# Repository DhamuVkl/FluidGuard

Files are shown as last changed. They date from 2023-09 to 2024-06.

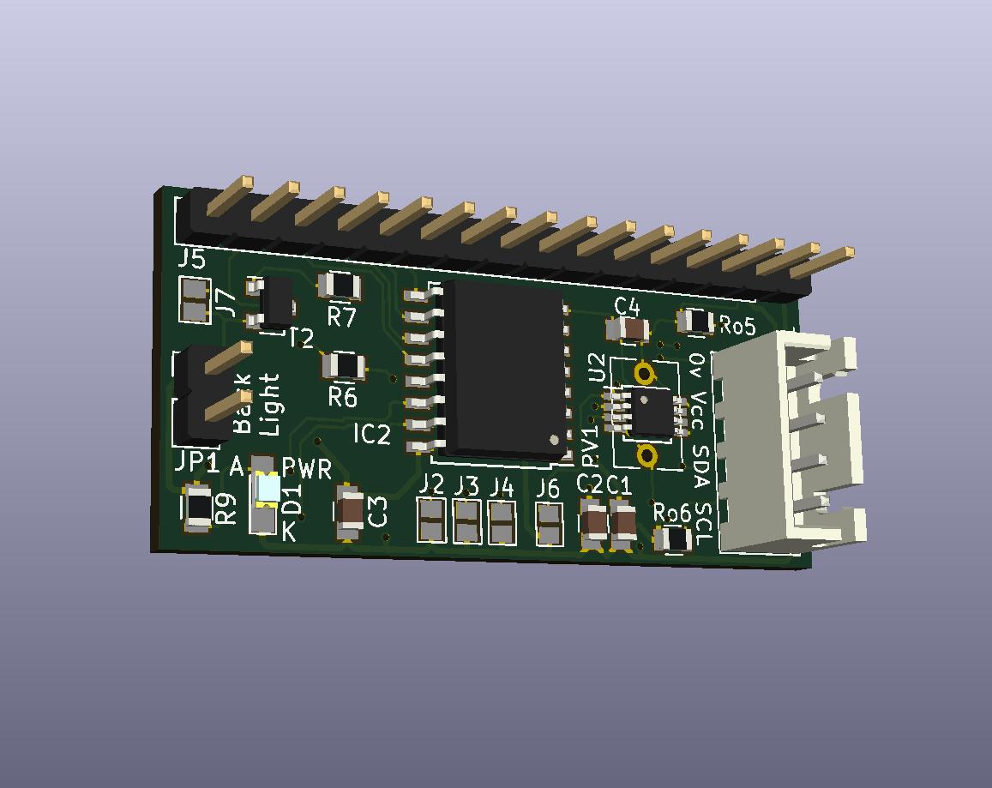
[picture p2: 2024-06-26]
FluidGuard-RX-PCB/Datasheets/I2C_LCD_Controller_Module-master/PCB/LCD_Controller/LCD_Controller3D.jpg

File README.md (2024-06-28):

<br/>
<p align="center">
  <a href="https://github.com/dhamuvkl/FluidGuard">
    
  </a>

  <h1 align="center">FluidGuard</h1>

  <p align="center">
    Envision a helpful companion that not only observes fluid levels but also takes proactive measures to prevent wastage and shortages!
    <br/>
    <br/>
  </p>
</p>

     

## Table Of Contents

* [About the Project](#about-the-project)
* [Key Features](#key-features)
* [Technologies Used](#technologies-used)
* [Schematics and Fabrication](#schematics-and-fabrication)
* [Roadmap](#roadmap)
* [Contributing](#contributing)
* [License](#license)
* [Conclusion](#conclusion)
* [Author](#author)

## About The Project



 <font size= “1”> **The FluidGuard:** </font> Intelligent Liquid Level Management and Refill Solution is akin to having a smart assistant for effectively managing liquids in tanks and containers. Envision a helpful companion that not only observes fluid levels but also takes proactive measures to prevent wastage and shortages, all the while being remarkably dependable and comprehensible. It tackles the challenges associated with manual fluid level management by seamlessly integrating an array of sensors, microcontrollers, wireless communication modules, and control mechanisms. This integration results in a sophisticated approach to fluid monitoring and regulation. Its significance shines in scenarios where precise fluid level management proves pivotal, such as within industrial, agricultural, and distant locations.

##  Key Features: 
coding

*	**Real-time Fluid Level Monitoring:** This system is engineered to monitor liquid levels across various environments, ranging from water tanks to industrial storage. By constantly gathering data from the fluid level sensor, it achieves precise and up-to-the-minute monitoring of fluid levels.
  
*	**Fail-safe Mechanisms:** To guarantee the system's integrity, fail-safe mechanisms are integrated. These mechanisms address potential issues such as data loss or transmission failures, ensuring the system remains operational and dependable.
  
*	**Error Detection and Correction:** The system's intelligence extends to error detection and real-time correction. It can identify sensor errors and implement corrective actions, contributing to its reliability and accuracy.
  
*	**Wireless Communication:** The NRF24L01+ PA/LNA modules serve as the communication backbone between the transmitting and receiving devices. These modules operate on a reliable wireless protocol, enabling seamless data transmission over distances, even in challenging environments.

*	**Automated Fluid Regulation:** Through relay components, the system automatically controls the pump to maintain fluid levels within pre-defined thresholds. This ensures efficient resource utilization and prevents overflows or depletion of the fluid source.
  
*	**User-friendly Interface:** The project incorporates a 16x2 LCD display that presents fluid levels visually using bars and percentages. This intuitive interface enhances user experience and simplifies the interpretation of fluid data.
  
*	**Versatility Across Storage Scenarios:** The system's adaptability makes it suitable for various storage scenarios, including silos and distant locations. Its wireless nature ensures that fluid data can be accessed and managed from a central location, saving time and resources.

## Technologies Used:
coding

*	**Microcontroller (Atmega 328p):** The microcontroller serves as the project's core, processing data from the sensor and facilitating communication with the wireless module.
  
*	**Wireless Communication (NRF24L01+ PA/LNA):**  These wireless modules are responsible for transmitting fluid level data from the transmitting device to the receiving device. The PA/LNA feature enhances the communication range and signal strength.
  
*	**Fluid Level Sensor (HC-SR04):** The HC-SR04 ultrasonic sensor accurately measures fluid levels. It emits ultrasonic signals and calculates the time taken for the signal to bounce back, providing a precise measurement of the distance to the fluid's surface.
  
*	**User Interface (16x2 LCD Display):** The LCD display translates numerical data into visual information, showing fluid levels in both bars and percentages. It offers an accessible way for users to interpret the data.
  
*	**Pump Control (Relay):** The relay component controls the pump's operation based on the received fluid level data. It ensures that the fluid level is maintained within the desired range.

## Schematics and Fabrication
### FluidGuard-RX



















### FluidGuard-TX














## Roadmap

See the [open issues](https://github.com/dhamuvkl/FluidGuard/issues) for a list of proposed features (and known issues).

## Contributing

Contributions are what make the open source community such an amazing place to be learn, inspire, and create. Any contributions you make are **greatly appreciated**.
* If you have suggestions for adding or removing projects, feel free to [open an issue](https://github.com/dhamuvkl/FluidGuard/issues/new) to discuss it, or directly create a pull request after you edit the *README.md* file with necessary changes.
* Please make sure you check your spelling and grammar.
* Create individual PR for each suggestion.


### Conclusion:

The Automated Liquid Level Indication and Refilling System is a testament to my proficiency in multiple domains, including microcontroller programming, wireless communication, sensor integration, and control mechanisms. By showcasing this project in my portfolio, I demonstrate my ability to develop innovative solutions that offer practical benefits in real-world scenarios. The fusion of technology, intelligent control, and user-friendly interfaces positions this project as a significant accomplishment in the field of automated fluid management.

## License

Distributed under the MIT License. See [LICENSE](https://github.com/dhamuvkl/FluidGuard/blob/main/LICENSE.md) for more information.

## Author

* **Dharageswaran S** - *Electronics Enthusiast | Innovator | Tech Visionary* - [Dharageswaran S](https://github.com/DhamuVkl/) - *Owner*

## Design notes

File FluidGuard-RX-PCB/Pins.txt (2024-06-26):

display lcd = i2c = 3
nrf = spi = 6
output control = 2
user input sw = 2
rotary = 3
load sensing = 2
power sensing = 1
serial debug = 2-3
uart = 2

ADC1 = 1 - 0.0475 190, 9.5
ADC2 = 3 - 0.1899 162, 38
ADC3 = 1 - 0.0475
ADC4 = 1 - 0.0475

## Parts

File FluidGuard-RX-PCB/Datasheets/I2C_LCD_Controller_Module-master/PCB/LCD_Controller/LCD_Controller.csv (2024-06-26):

Source: | C:/Users/Win 7/Documents/KiCAD/LCD_Controller/LCD_Controller.sch
Date: | 26/11/2018 11:17
Tool: | Eeschema 4.0.7
Component Count: | 38
Ref | Value | Footprint | Datasheet | Manufacturer | Vendor
C1 | 1uF Ceramic | Capacitors_SMD:C_0805
C2 | 1uF Ceramic | Capacitors_SMD:C_0805
C3 | 0.1uF | Capacitors_SMD:C_0805
C4 | 0.1uF | Capacitors_SMD:C_0805
C5 | 0.1uF | Capacitors_SMD:C_0805
D1 | RED LED | LEDs:LED_0805_HandSoldering
IC1 | XC6206 | TO_SOT_Packages_SMD:SOT-23
IC2 | PCF8574A | Housings_SOIC:SOIC-16W_7.5x10.3mm_Pitch1.27mm
J1 | LCD | Connectors_JST:JST_XH_B04B-XH-A_04x2.50mm_Straight
J2 | GS2 | Connectors:GS2
J3 | GS2 | Connectors:GS2
J4 | GS2 | Connectors:GS2
J5 | To LCD | Pin_Headers:Pin_Header_Straight_1x16_Pitch2.54mm
J6 | GS2 | Connectors:GS2
J7 | GS2 | Connectors:GS2
JP1 | Jumper | Pin_Headers:Pin_Header_Straight_1x02_Pitch2.54mm
Q1 | DMG3414U | TO_SOT_Packages_SMD:SOT-23
Q2 | DMG3414U | TO_SOT_Packages_SMD:SOT-23
R1 | 10K | Resistors_SMD:R_0805
R2 | 10K | Resistors_SMD:R_0805
R3 | 1K | Resistors_SMD:R_0805
R4 | 10K | Resistors_SMD:R_0805
R5 | 10K | Resistors_SMD:R_0805
R6 | 1K | Resistors_SMD:R_0805
R7 | 1K | Resistors_SMD:R_0805
R9 | 1K | Resistors_SMD:R_0805
ROpt1 | 4K7 | Resistors_SMD:R_0805
ROpt2 | 4K7 | Resistors_SMD:R_0805
ROpt3 | 0R | Resistors_SMD:R_0805
ROpt4 | 0R | Resistors_SMD:R_0805
ROpt5 | 4K7 | Resistors_SMD:R_0805
ROpt6 | 4K7 | Resistors_SMD:R_0805
RV1 | 10K | Potentiometers:Potentiometer_Trimmer_Vishay_T73XW_Vertical
T1 | BCW66GLT1G | TO_SOT_Packages_SMD:SOT-23
T2 | BC858C | TO_SOT_Packages_SMD:SOT-23
T3 | BCW66GLT1G | TO_SOT_Packages_SMD:SOT-23
U1 | ATTINY85-20PU | Housings_SOIC:SO-8_5.3x6.2mm_Pitch1.27mm
U2 | MCP4561-103E/MS | Housings_SSOP:MSOP-8_3x3mm_Pitch0.65mm

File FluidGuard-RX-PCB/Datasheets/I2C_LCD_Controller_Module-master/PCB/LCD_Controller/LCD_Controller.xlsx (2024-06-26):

Source: | C:/Users/Win 7/Documents/KiCAD/LCD_Controller/LCD_Controller.sch
Date: | 2018-11-26 11:17
Tool: | Eeschema 4.0.7
Component Count: | 38
Ref | Value | Footprint | Status | Location | Order | Supplier | Cat. No. | Manufacturer | Part No. | Cost | Datasheet
C1 | 1uF Ceramic @ 25v | Capacitors_SMD:C_0805 | Fitted | T | 6 | FEC | 2896566 | Vishay | VJ0805Y105KXXTW1BC | 0.061 | http://www.farnell.com/datasheets/2620235.pdf
C2 | 1uF Ceramic @ 25v | Capacitors_SMD:C_0805 | Not Fitted | T | N/A | N/A | N/A | N/A | N/A | N/A | N/A
C3 | 0.1uF | Capacitors_SMD:C_0805 | Fitted | T | 7 | FEC | 2332715 | AVX | 08051C104JAT2A | 0.18 | http://www.farnell.com/datasheets/2237835.pdf
C4 | 0.1uF | Capacitors_SMD:C_0805 | Fitted | T | 8 | FEC | 2332715 | AVX | 08051C104JAT2A | 0.18 | http://www.farnell.com/datasheets/2237835.pdf
C5 | 0.1uF | Capacitors_SMD:C_0805 | Fitted | B | 8 | FEC | 2332715 | AVX | 08051C104JAT2A | 0.18 | http://www.farnell.com/datasheets/2237835.pdf
D1 | RED LED | LEDs:LED_0805_HandSoldering | Fitted | T | 9 | FEC | 2290331 | KINGBRIGHT | KP-2012CGCK | 0.0564 | http://www.farnell.com/datasheets/2045817.pdf
IC1 | XC6206 | TO_SOT_Packages_SMD:SOT-23 | Not Fitted | B | N/A | N/A | N/A | N/A | N/A | N/A | N/A
IC2 | PCF8574A | Housings_SOIC:SOIC-16W_7.5x10.3mm_Pitch1.27mm | Fitted | T | 12 | FEC | 2407150 | TI | PCF8574ADWR | 0.942 | http://www.ti.com/lit/ds/symlink/pcf8574a.pdf
J1 | LCD | Connectors_JST:JST_XH_B04B-XH-A_04x2.50mm_Straight | Fitted | T | 15 | Ebay | N/A | JST | XH | 3.19 | https://www.ebay.co.uk/itm/60-Sets-JST-XH-2-54mm-2-3-4Pin-Male-and-Female-Housing-Connector-with-Crimp-LuH/223092217345
J2 | GS2 | Connectors:GS2 | Not Fitted | T | N/A | N/A | N/A | N/A | N/A | N/A | N/A
J3 | GS2 | Connectors:GS2 | Not Fitted | T | N/A | N/A | N/A | N/A | N/A | N/A | N/A
J4 | GS2 | Connectors:GS2 | Not Fitted | T | N/A | N/A | N/A | N/A | N/A | N/A | N/A
J5 | To LCD | Pin_Headers:Pin_Header_Straight_1x16_Pitch2.54mm | Fitted | B | 12 | Ebay | https://www.ebay.co.uk/itm/50PCS-40Pin-Header-Connector-2-54mm-Single-Row-Male-Pin-Header-Strip-F4F7P/143030634420 | Molex | N/A | 0.0486 | https://www.ebay.co.uk/itm/50PCS-40Pin-Header-Connector-2-54mm-Single-Row-Male-Pin-Header-Strip-F4F7P/143030634420
J6 | GS2 | Connectors:GS2 | Fitted | T | 10 | N/A | N/A | N/A | N/A | N/A | N/A
J7 | GS2 | Connectors:GS2 | Not Fitted | T | N/A | N/A | N/A | N/A | N/A | N/A | N/A
JP1 | Jumper | Pin_Headers:Pin_Header_Straight_1x02_Pitch2.54mm | Fitted | T | 14 | Ebay | https://www.ebay.co.uk/itm/50PCS-40Pin-Header-Connector-2-54mm-Single-Row-Male-Pin-Header-Strip-F4F7P/143030634420 | Molex | N/A | 0.0486 | https://www.ebay.co.uk/itm/50PCS-40Pin-Header-Connector-2-54mm-Single-Row-Male-Pin-Header-Strip-F4F7P/143030634420
Q1 | DMG3414U | TO_SOT_Packages_SMD:SOT-23 | Not Fitted | B | N/A | FEC | 2061404 | DIODES INC. | DMG3414U | 0.238 | http://www.farnell.com/datasheets/1915878.pdf
Q2 | DMG3414U | TO_SOT_Packages_SMD:SOT-23 | Not Fitted | B | N/A | FEC | 2061404 | DIODES INC. | DMG3414U | 0.238 | http://www.farnell.com/datasheets/1915878.pdf
R1 | 10K | Resistors_SMD:R_0805 | Fitted | B | 1 | FEC | 1652909 | Vishay | CRCW080510K0FKTA | 0.139 | http://www.farnell.com/datasheets/2310790.pdf
R2 | 10K | Resistors_SMD:R_0805 | Fitted | B | 2 | FEC | 1652909 | Vishay | CRCW080510K0FKTA | 0.139 | http://www.farnell.com/datasheets/2310790.pdf
R3 | 1K | Resistors_SMD:R_0805 | Fitted | B | 3 | FEC | 1652937 | Vishay | CRCW08051K00JNEA | 0.0373 | http://www.farnell.com/datasheets/2310790.pdf
R4 | 10K | Resistors_SMD:R_0805 | Fitted | B | 4 | FEC | 1652909 | Vishay | CRCW080510K0FKTA | 0.139 | http://www.farnell.com/datasheets/2310790.pdf
R5 | 10K | Resistors_SMD:R_0805 | Fitted | B | 5 | FEC | 1652909 | Vishay | CRCW080510K0FKTA | 0.139 | http://www.farnell.com/datasheets/2310790.pdf
R6 | 1K | Resistors_SMD:R_0805 | Fitted | T | 1 | FEC | 1652937 | Vishay | CRCW08051K00JNEA | 0.0373 | http://www.farnell.com/datasheets/2310790.pdf
R7 | 1K | Resistors_SMD:R_0805 | Fitted | T | 2 | FEC | 1652937 | Vishay | CRCW08051K00JNEA | 0.0373 | http://www.farnell.com/datasheets/2310790.pdf
R9 | 1K | Resistors_SMD:R_0805 | Fitted | T | 3 | FEC | 1652937 | Vishay | CRCW08051K00JNEA | 0.0373 | http://www.farnell.com/datasheets/2310790.pdf
ROpt1 | 4K7 | Resistors_SMD:R_0805 | Not Fitted | B | N/A | FEC | 1469923 | Vishay | CRCW08054K70FKEA | 0.0587 | http://www.farnell.com/datasheets/2310790.pdf
ROpt2 | 4K7 | Resistors_SMD:R_0805 | Not Fitted | B | N/A | FEC | 1469923 | Vishay | CRCW08054K70FKEA | 0.0587 | http://www.farnell.com/datasheets/2310790.pdf
ROpt3 | 0R | Resistors_SMD:R_0805 | Fitted | B | 6 | FEC | 2073603 | MULTICOMP | MCMR08X000 PTL | 0.0132 | http://www.farnell.com/datasheets/2549522.pdf
ROpt4 | 0R | Resistors_SMD:R_0805 | Fitted | B | 7 | FEC | 2073603 | MULTICOMP | MCMR08X000 PTL | 0.0132 | http://www.farnell.com/datasheets/2549522.pdf
ROpt5 | 4K7 | Resistors_SMD:R_0805 | Fitted | T | 4 | FEC | 1469923 | Vishay | CRCW08054K70FKEA | 0.0587 | http://www.farnell.com/datasheets/2310790.pdf
ROpt6 | 4K7 | Resistors_SMD:R_0805 | Fitted | T | 5 | FEC | 1469923 | Vishay | CRCW08054K70FKEA | 0.0587 | http://www.farnell.com/datasheets/2310790.pdf
RV1 | 10K | Potentiometers:Potentiometer_Trimmer_Vishay_T73XW_Vertical | Not Fitted | T | N/A | FEC | 1357152 | Vishay | T73YU103KT20 | 0.707 | http://www.farnell.com/datasheets/2243711.pdf
T1 | BCW66GLT1G | TO_SOT_Packages_SMD:SOT-23 | Fitted | B | 9 | FEC | 2317524 | On Semi | BCW66GLT1G | 0.13 | http://www.farnell.com/datasheets/2354268.pdf
T2 | BC858C | TO_SOT_Packages_SMD:SOT-23 | Fitted | T | 13 | FEC | 1574345 | Multicomp | BC858C | 0.132 | http://www.farnell.com/datasheets/1850915.pdf
T3 | BCW66GLT1G | TO_SOT_Packages_SMD:SOT-23 | Fitted | B | 10 | FEC | 2317524 | On Semi | BCW66GLT1G | 0.13 | http://www.farnell.com/datasheets/2354268.pdf
U1 | ATTINY85-20PU | Housings_SOIC:SO-8_5.3x6.2mm_Pitch1.27mm | Fitted | B | 11 | FEC | 2774978 | MICROCHIP | ATTINY85-20SF | 1.01 | http://www.farnell.com/datasheets/1738893.pdf
U2 | MCP4561-103E/MS | Housings_SSOP:MSOP-8_3x3mm_Pitch0.65mm | Fitted | T | 11 | FEC | 1698948 | MICROCHIP | MCP4561-103E/MS | 0.749 | http://www.farnell.com/datasheets/2243913.pdf
 | Jumper Link for JP1 | N/A | N/A | N/A | N/A | FEC | 150410 | HARWIN | M7567-05 | 0.119 | http://www.farnell.com/datasheets/2368224.pdf
 |  |  |  |  |  |  |  |  |  | 6.958
 | Comment : For 5v I2C operation with SDA, SCL 4K4 Pullups

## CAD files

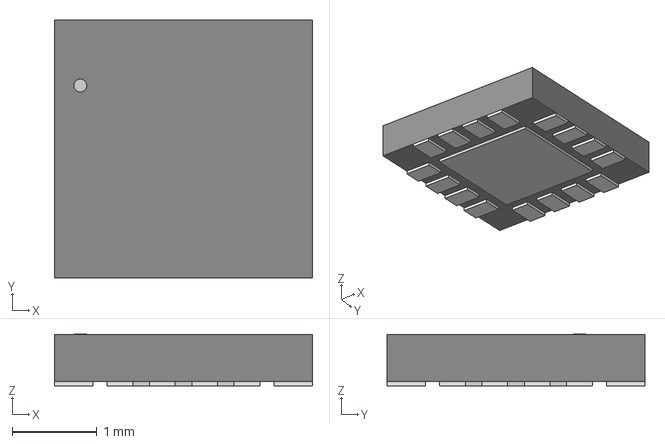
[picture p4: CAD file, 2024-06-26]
FluidGuard-RX-PCB/#Library/RFX2401C-PA-LNA/RFX2401C_SKY.step
3.05 x 3.05 x 0.612 mm

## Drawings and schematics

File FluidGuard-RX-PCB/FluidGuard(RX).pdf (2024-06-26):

A

B

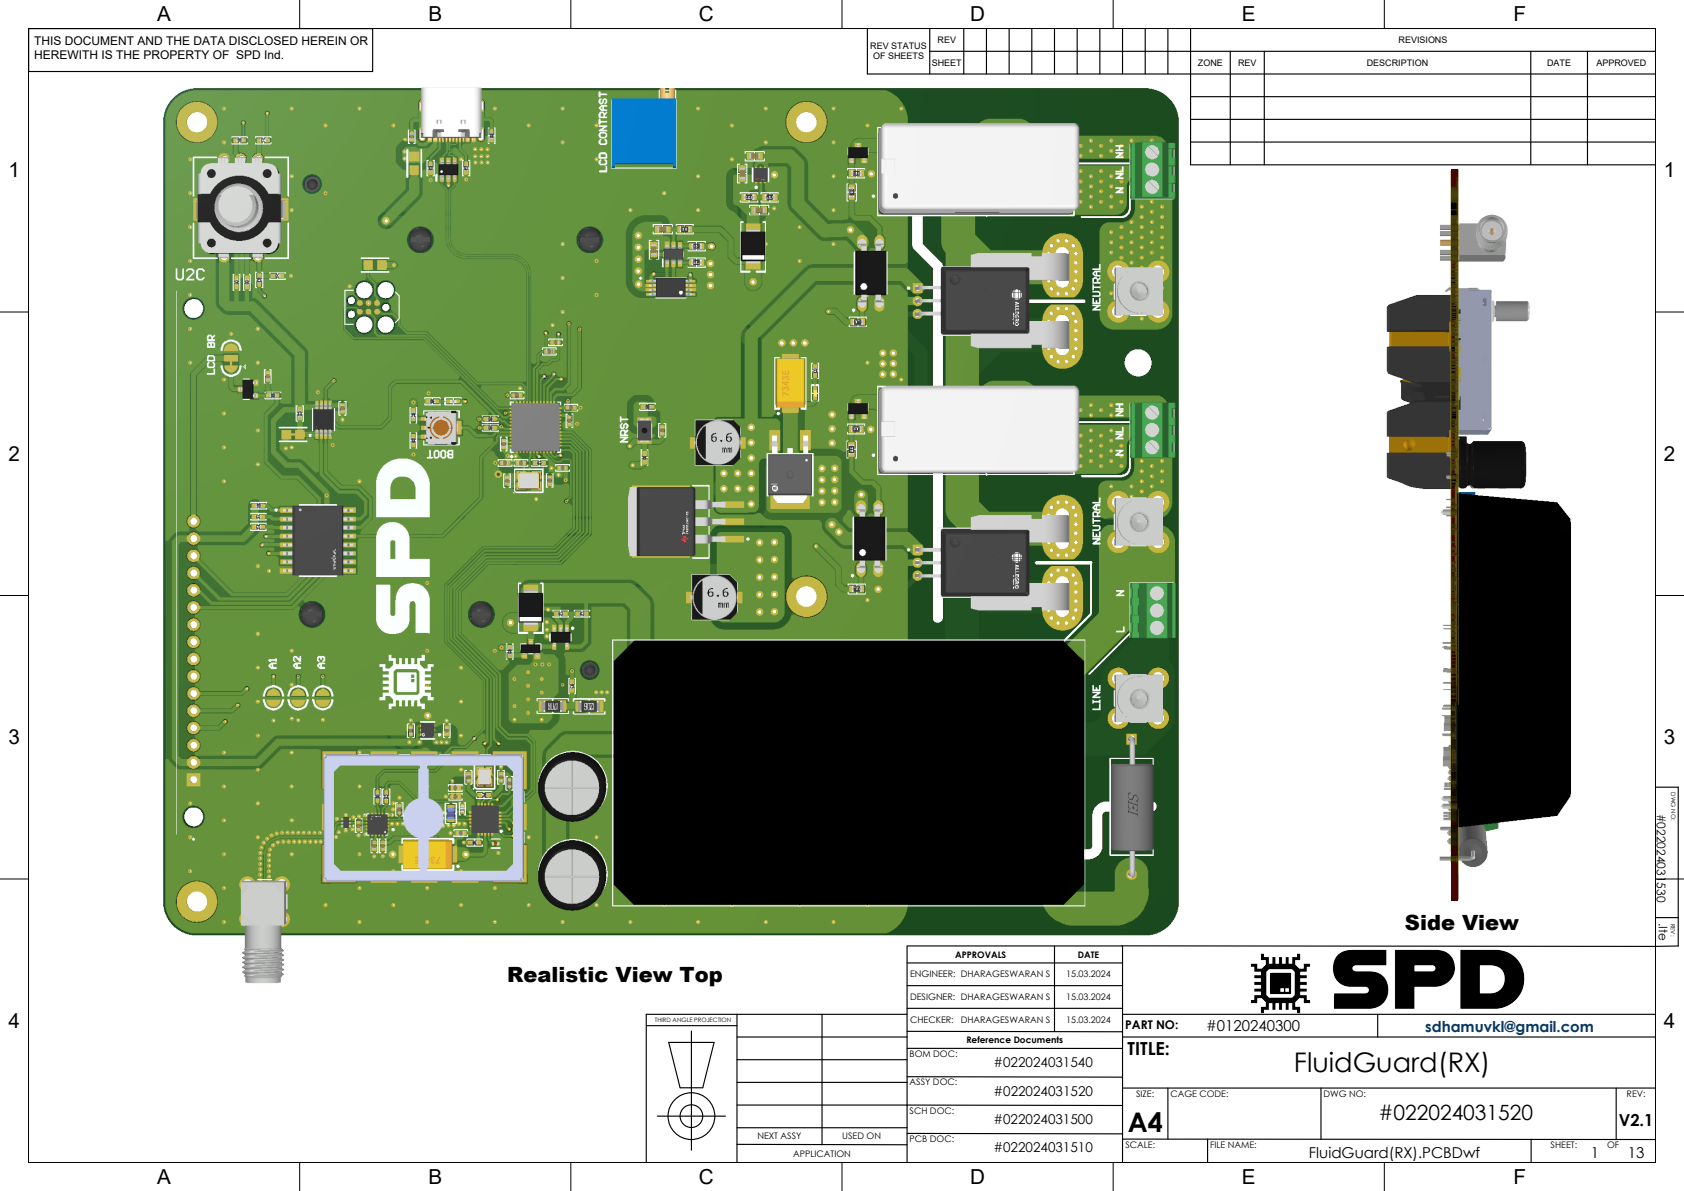
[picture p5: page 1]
sdhamuvkl@gmail.com; ZONE; REV; DESCRIPTION; DATE; APPROVED; REVISIONS; SHEET; REV STATUS OF SHEETS; REV:; SHEET:; DWG NO: #022024031530 .Ite; PART NO:; NEXT ASSY; USED ON; APPLICATION; FluidGuard(RX).PCBDwf #022024031510; FILE NAME:; Reference Documents #022024031540; SCH DOC:; PCB DOC:; ASSY DOC:; BOM DOC:; FluidGuard(RX); TITLE:; SCALE:; DWG NO:; SIZE:; CAGE CODE:; Side View

THIS DOCUMENT AND THE DATA DISCLOSED HEREIN OR
HEREWITH IS THE PROPERTY OF SPD Ind.

APPROVALS | DATE

Realistic View Top

ENGINEER: DHARAGESWARAN S | 15.03.2024

DESIGNER: DHARAGESWARAN S | 15.03.2024

THIRD ANGLE PROJECTION

CHECKER: DHARAGESWARAN S | 15.03.2024

1 | 1

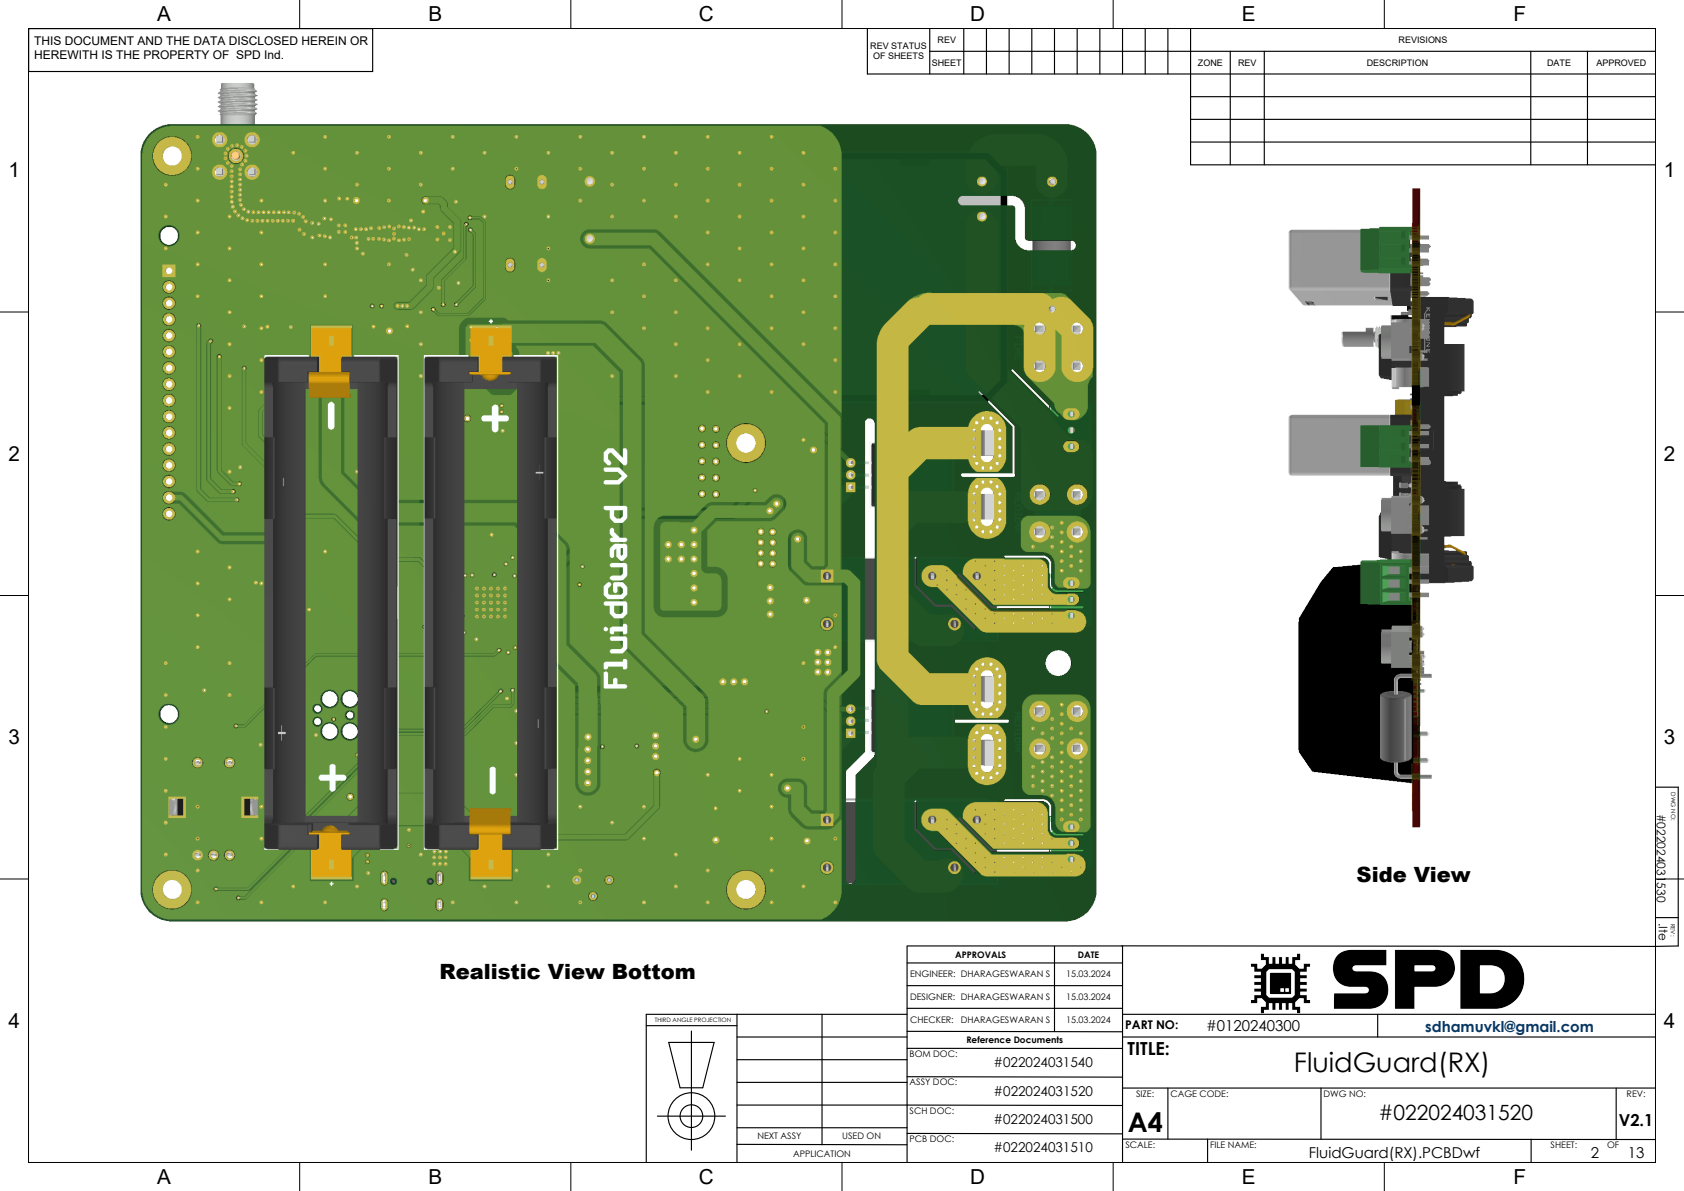
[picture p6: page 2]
sdhamuvkl@gmail.com; DWG NO: #022024031530 .Ite; REV:; PART NO:; Reference Documents #022024031540; ASSY DOC:; BOM DOC:; FluidGuard(RX); TITLE:; Side View

APPROVALS | DATE

Realistic View Bottom

ENGINEER: DHARAGESWARAN S | 15.03.2024

DESIGNER: DHARAGESWARAN S | 15.03.2024

THIRD ANGLE PROJECTION

CHECKER: DHARAGESWARAN S | 15.03.2024

1 | 1

1

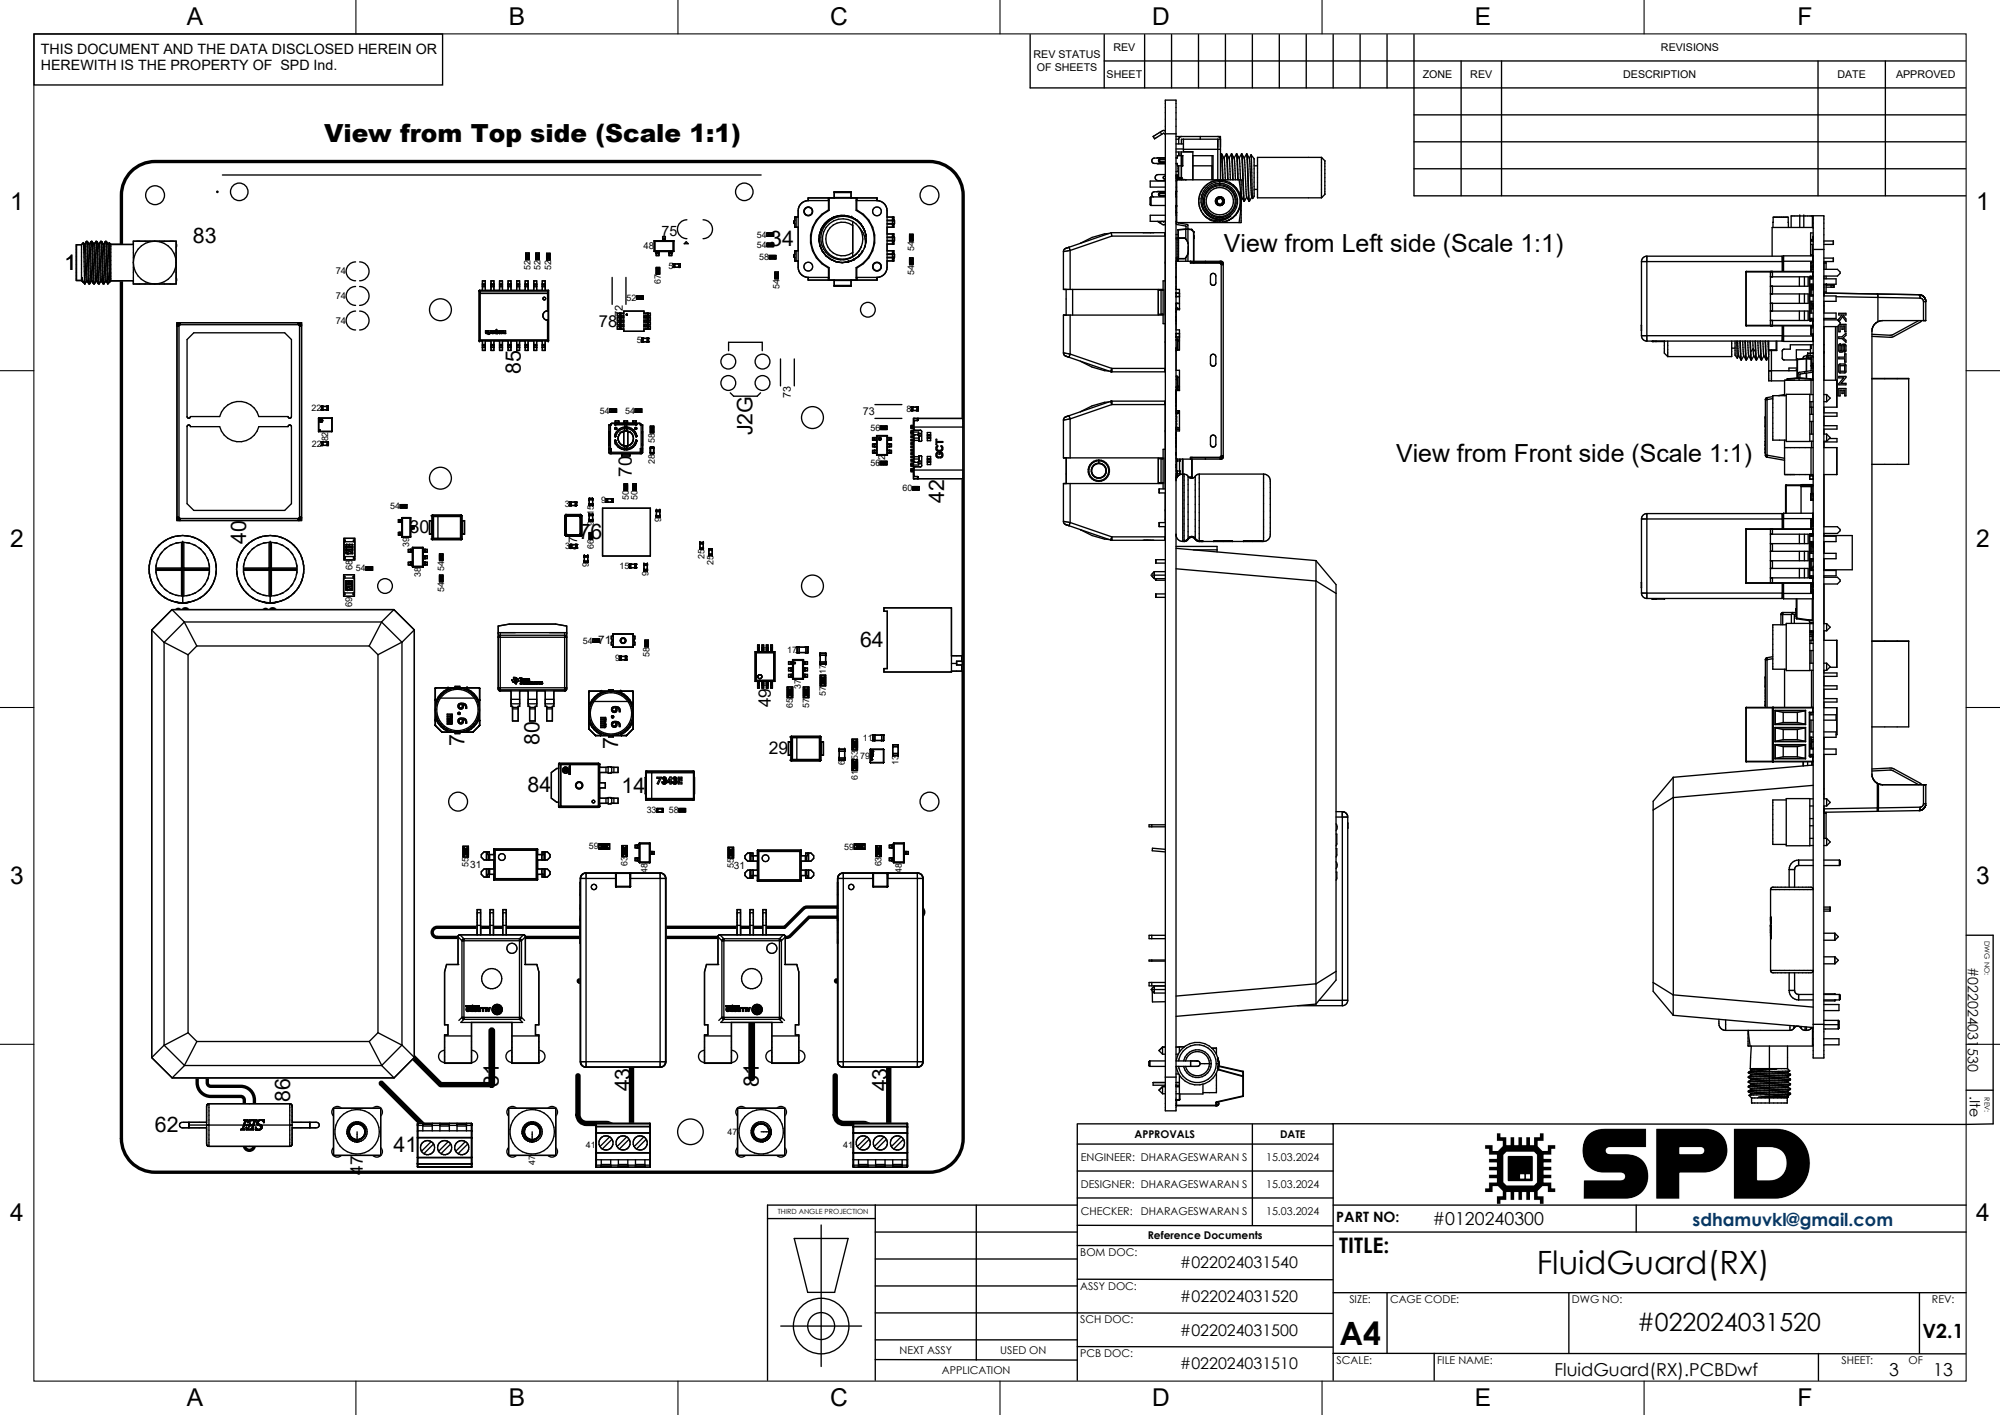
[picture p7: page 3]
DWG NO: #022024031530 .Ite; REV:; DHARAGESWARAN S; CHECKER:; DESIGNER:; ENGINEER:; APPROVALS; DATE; PART NO:; Reference Documents #022024031540; ASSY DOC:; BOM DOC:; FluidGuard(RX); TITLE:

View from Top side (Scale 1:1)

View from Left side (Scale 1:1)

View from Front side (Scale 1:1)

THIRD ANGLE PROJECTION

sdhamuvkl@gmail.com

1 | 1

# Drill Drawing View (Scale 1:1)

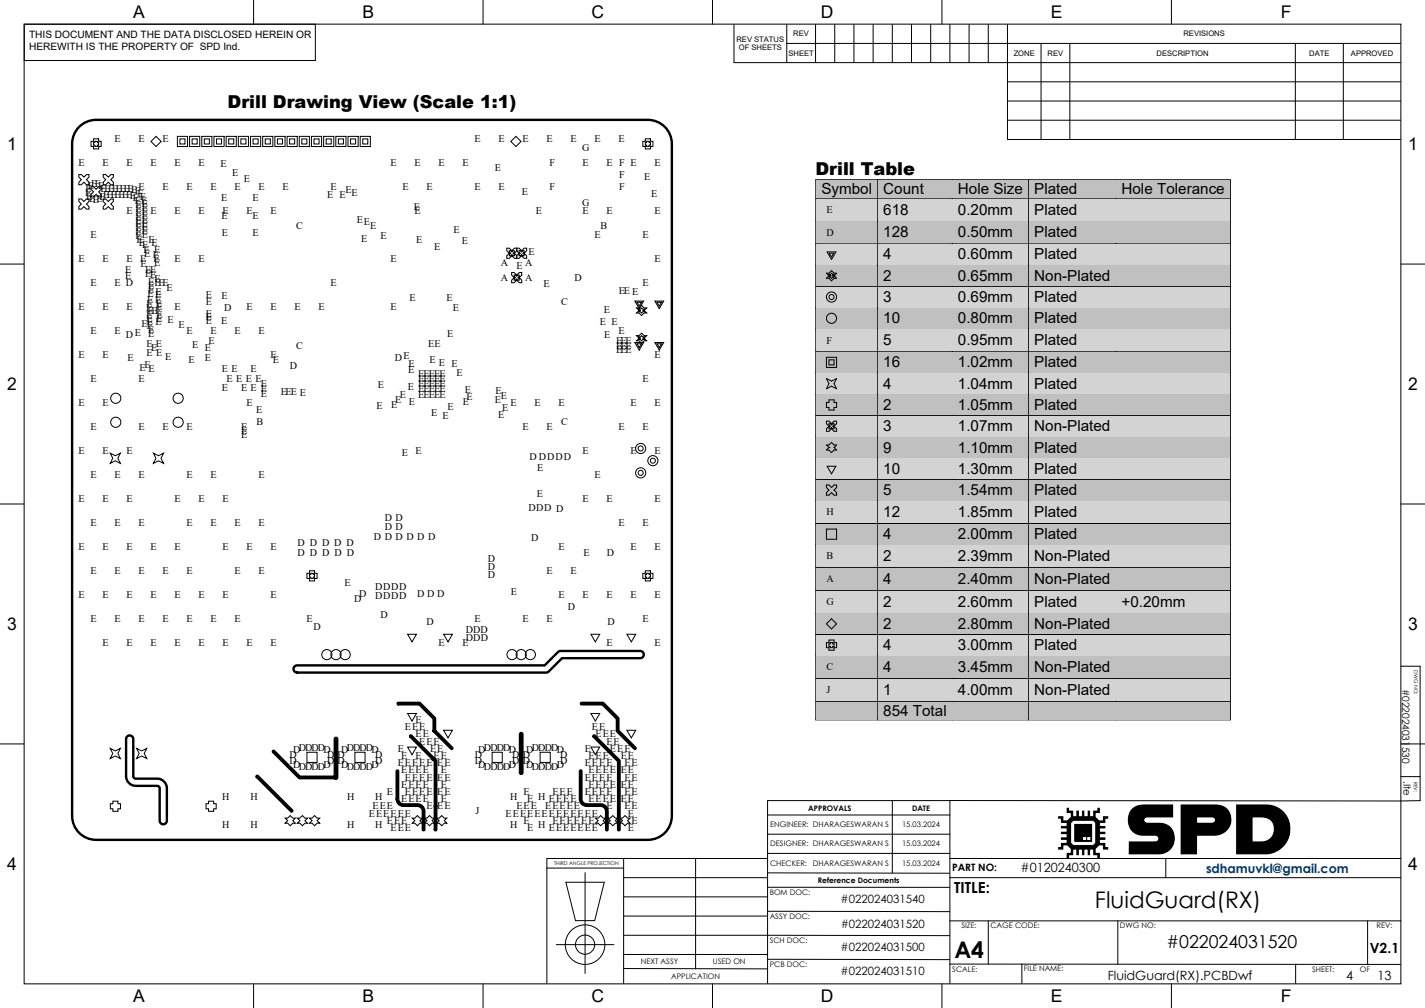
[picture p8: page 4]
D DDDD; DDD D; DD DDDD; DDD DDD; DDDD; EEE; EEEEE; EEE E; EEEE; EEEEE EEEEE EEEEE EEEEE EEEEE; DWG NO: #022024031530 .Ite; REV:; PART NO:; Reference Documents #022024031540; ASSY DOC:; BOM DOC:; FluidGuard(RX); TITLE:; Drill Table

Symbol | Count | Hole Size | Plated | Hole Tolerance
E | 618 | 0.20mm | Plated

D | 128 | 0.50mm | Plated

4 | 0.60mm | Plated
2 | 0.65mm | Non-Plated
3 | 0.69mm | Plated
10 | 0.80mm | Plated

F | 5 | 0.95mm | Plated

16 | 1.02mm | Plated
4 | 1.04mm | Plated
2 | 1.05mm | Plated
3 | 1.07mm | Non-Plated
9 | 1.10mm | Plated
10 | 1.30mm | Plated
5 | 1.54mm | Plated

H | | | 12 | 1.85mm | Plated

4 | 2.00mm | Plated

B | | | 2 | 2.39mm | Non-Plated

A | | | 4 | 2.40mm | Non-Plated

G | | | 2 | 2.60mm | Plated | +0.20mm

2 | 2.80mm | Non-Plated
4 | 3.00mm | Plated

C | | | 4 | 3.45mm | Non-Plated

J | | | 1 | 4.00mm | Non-Plated

854 Total

APPROVALS | DATE

ENGINEER: DHARAGESWARAN S | 15.03.2024

DESIGNER: DHARAGESWARAN S | 15.03.2024

THIRD ANGLE PROJECTION

CHECKER: DHARAGESWARAN S | 15.03.2024

sdhamuvkl@gmail.com

1 | 1
Material | Layer | Thickness Dielectric Material Type | Gerber

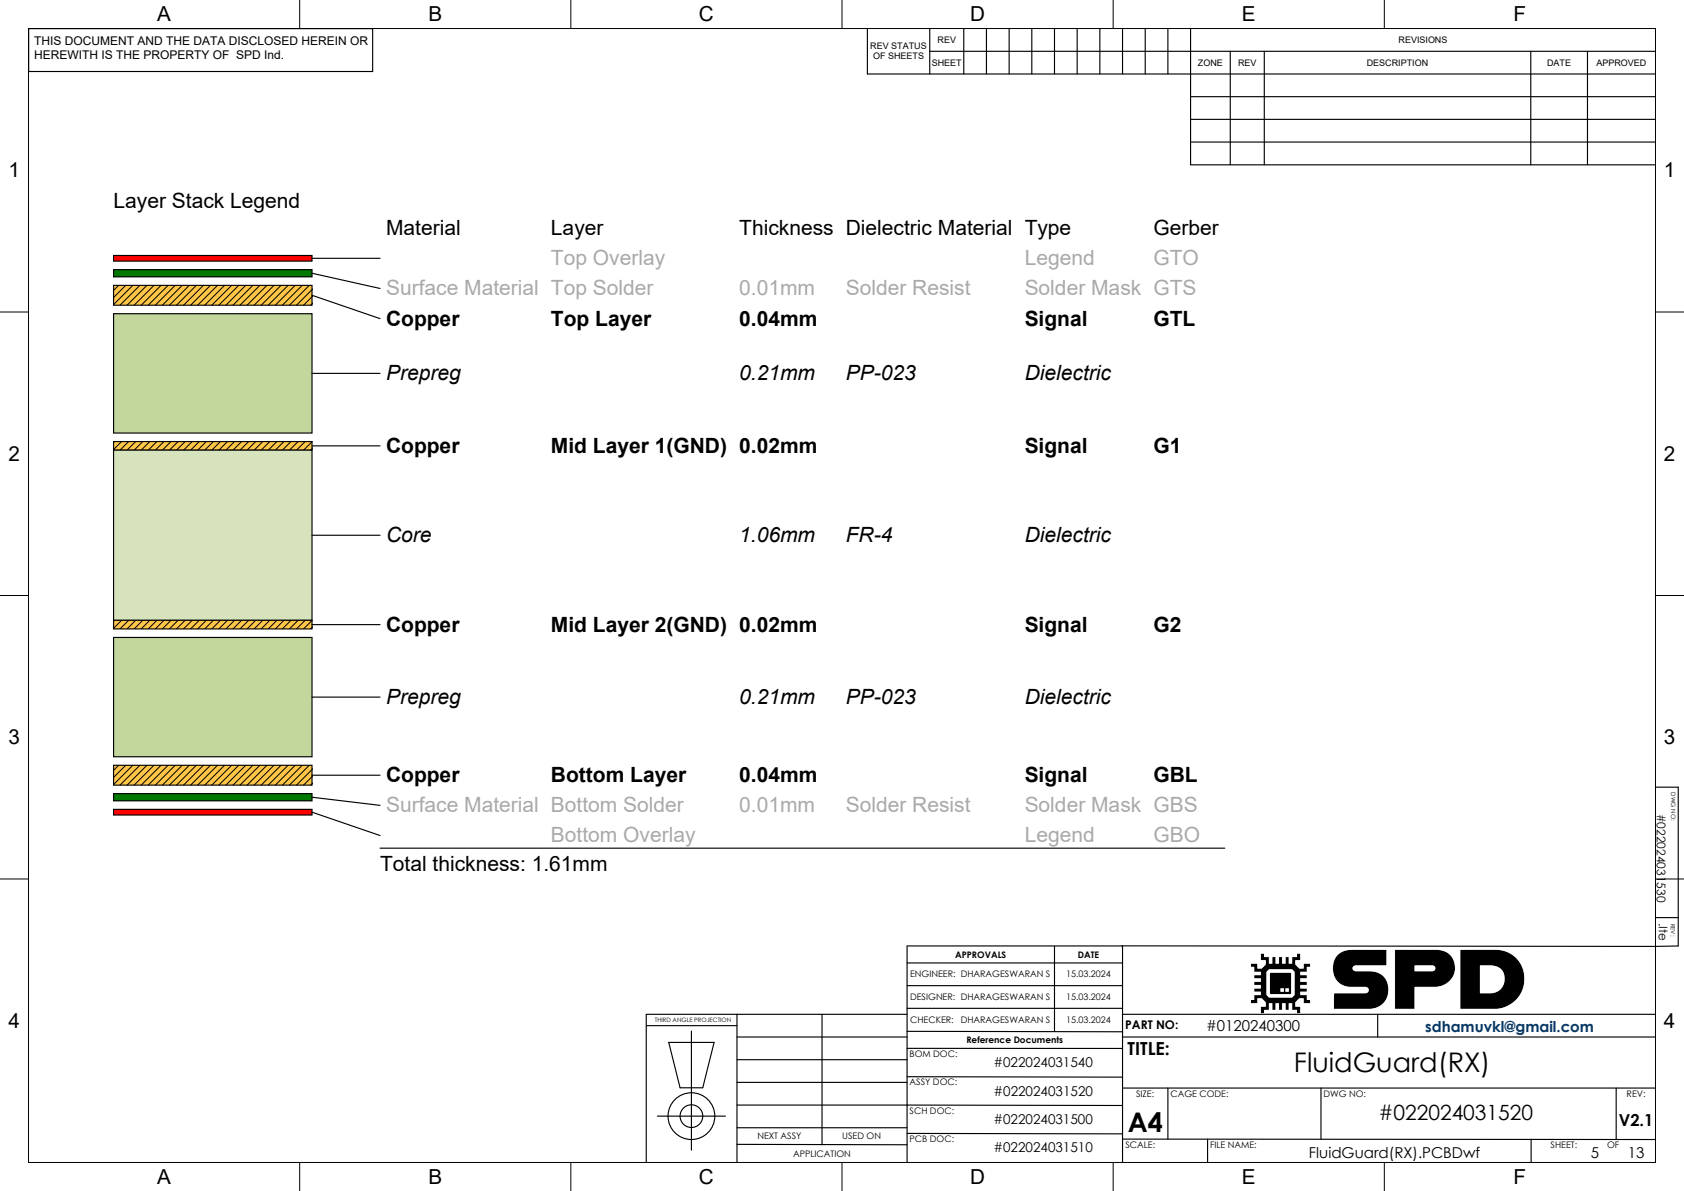
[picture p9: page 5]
sdhamuvkl@gmail.com; DWG NO: #022024031530 .Ite; REV:; PART NO:; Reference Documents #022024031540; ASSY DOC:; BOM DOC:; FluidGuard(RX); TITLE:; Top Overlay; Legend; GTO; Surface Material Top Solder; Solder Resist; Solder Mask GTS; Copper; Top Layer; Signal; GTL; Prepreg; Dielectric; Mid Layer 1(GND) 0.02mm; Core; Mid Layer 2(GND) 0.02mm; Bottom Layer; GBL; Surface Material Bottom Solder; Solder Mask GBS; Bottom Overlay; GBO; Total thickness: 1.61mm

Layer Stack Legend

APPROVALS | DATE

ENGINEER: DHARAGESWARAN S | 15.03.2024

DESIGNER: DHARAGESWARAN S | 15.03.2024

THIRD ANGLE PROJECTION

CHECKER: DHARAGESWARAN S | 15.03.2024

1 | 1

A

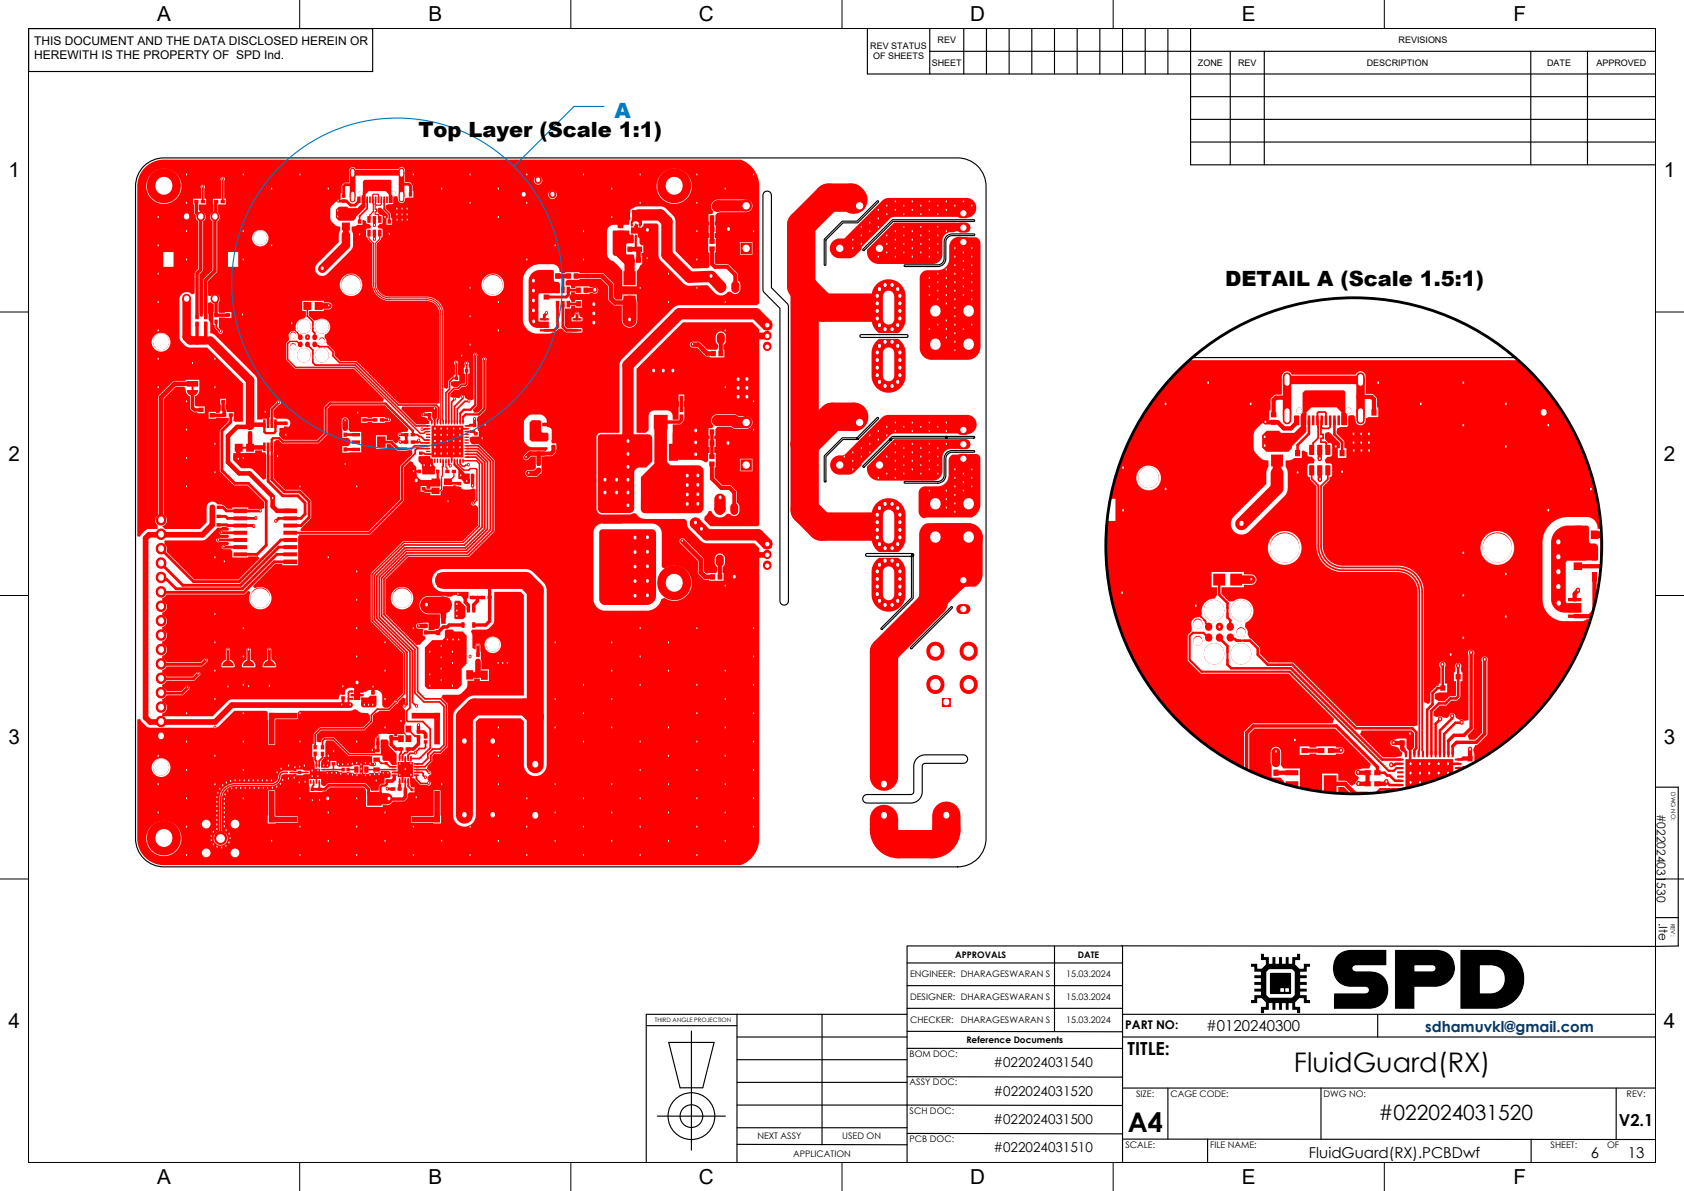
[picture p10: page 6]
DWG NO: #022024031530 .Ite; REV:; PART NO:; Reference Documents #022024031540; ASSY DOC:; BOM DOC:; FluidGuard(RX); TITLE:; DETAIL A (Scale 1.5:1)

Top Layer (Scale 1:1)

APPROVALS | DATE

ENGINEER: DHARAGESWARAN S | 15.03.2024

DESIGNER: DHARAGESWARAN S | 15.03.2024

THIRD ANGLE PROJECTION

CHECKER: DHARAGESWARAN S | 15.03.2024

sdhamuvkl@gmail.com

1 | 1

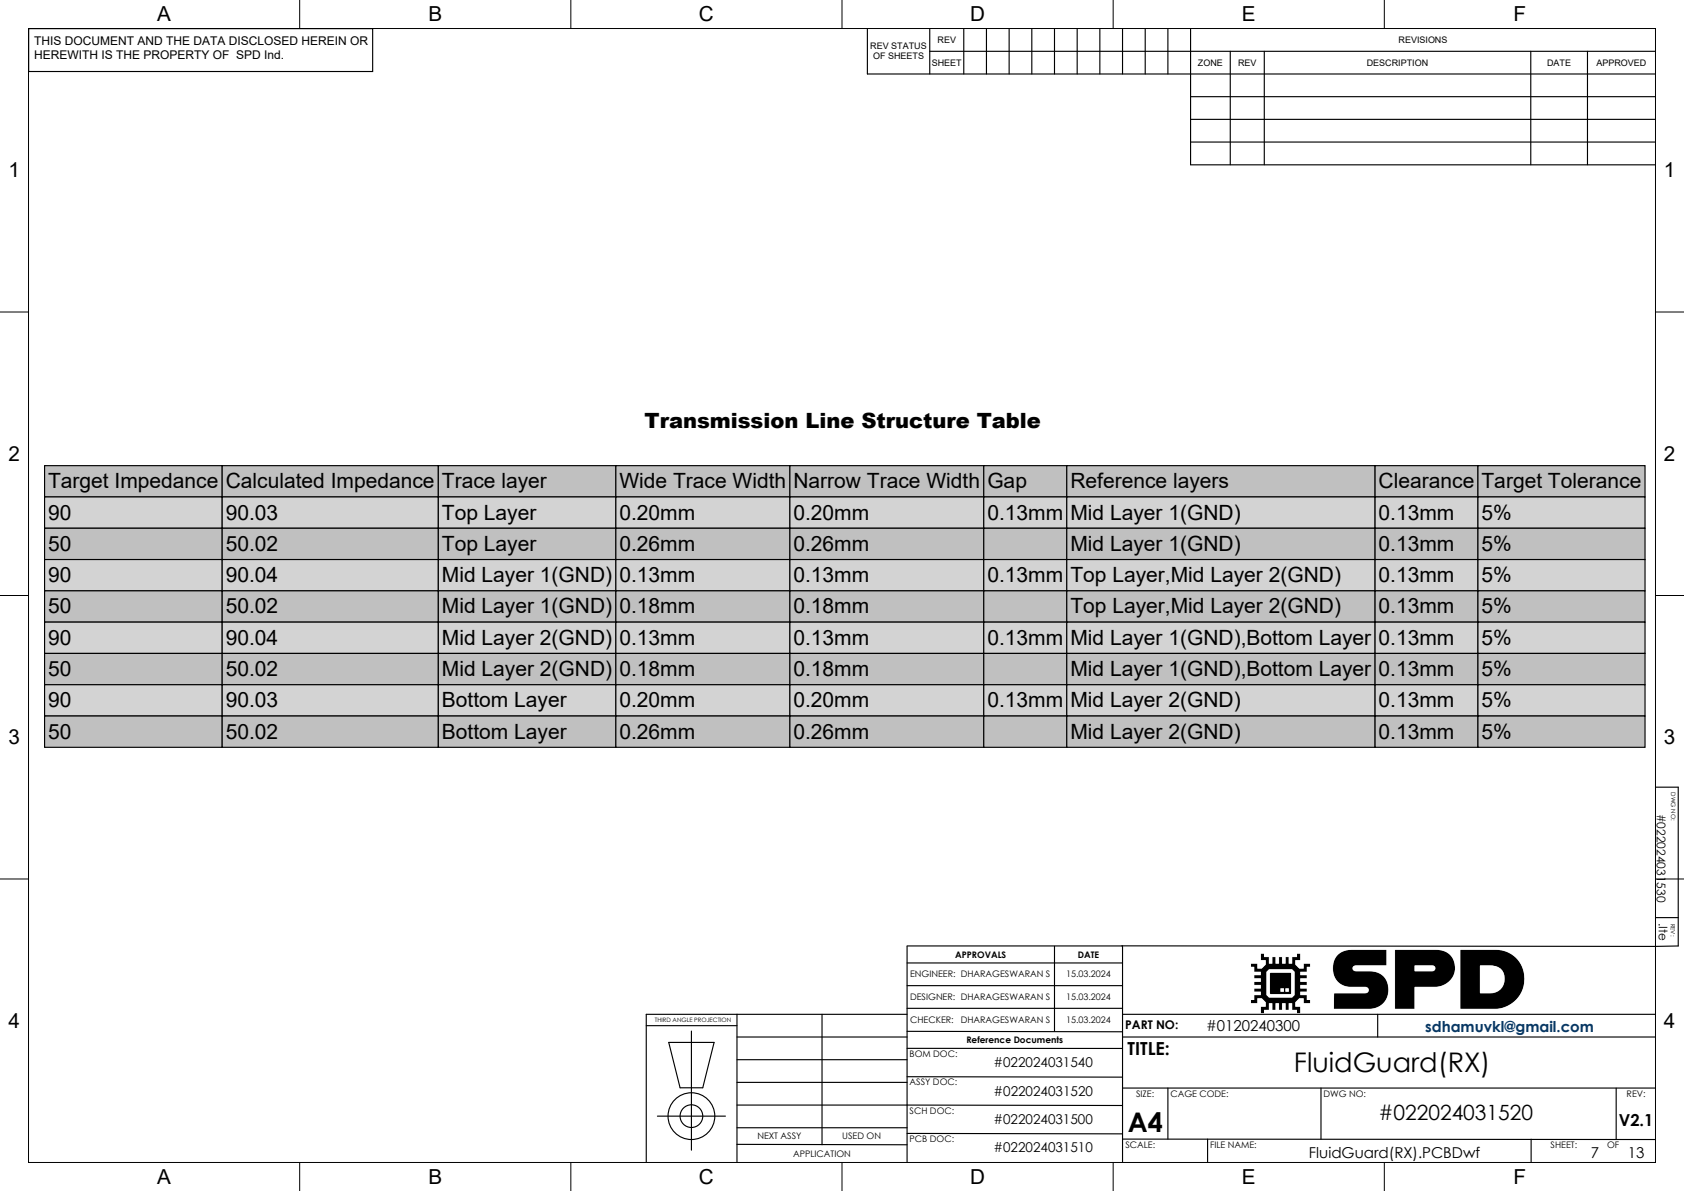
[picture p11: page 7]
sdhamuvkl@gmail.com; DWG NO: #022024031530 .Ite; REV:; PART NO:; Reference Documents #022024031540; ASSY DOC:; BOM DOC:; FluidGuard(RX); TITLE:; Target Impedance 90 50 90 50 90 50 90 50; Calculated Impedance 90.03 50.02 90.04 50.02 90.04 50.02 90.03 50.02; Wide Trace Width 0.20mm 0.26mm 0.13mm 0.18mm 0.13mm 0.18mm 0.20mm 0.26mm; Narrow Trace Width 0.20mm 0.26mm 0.13mm 0.18mm 0.13mm 0.18mm 0.20mm 0.26mm; Gap 0.13mm; Clearance 0.13mm 0.13mm 0.13mm 0.13mm 0.13mm 0.13mm 0.13mm 0.13mm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

Transmission Line Structure Table

Trace layer
Top Layer
Mid Layer 1(GND)
Mid Layer 2(GND)
Bottom Layer

Reference layers
Top Layer,Mid Layer 2(GND)
Mid Layer 1(GND),Bottom Layer

APPROVALS | DATE

ENGINEER: DHARAGESWARAN S | 15.03.2024

DESIGNER: DHARAGESWARAN S | 15.03.2024

THIRD ANGLE PROJECTION

CHECKER: DHARAGESWARAN S | 15.03.2024
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

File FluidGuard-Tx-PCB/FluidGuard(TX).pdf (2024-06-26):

A

B

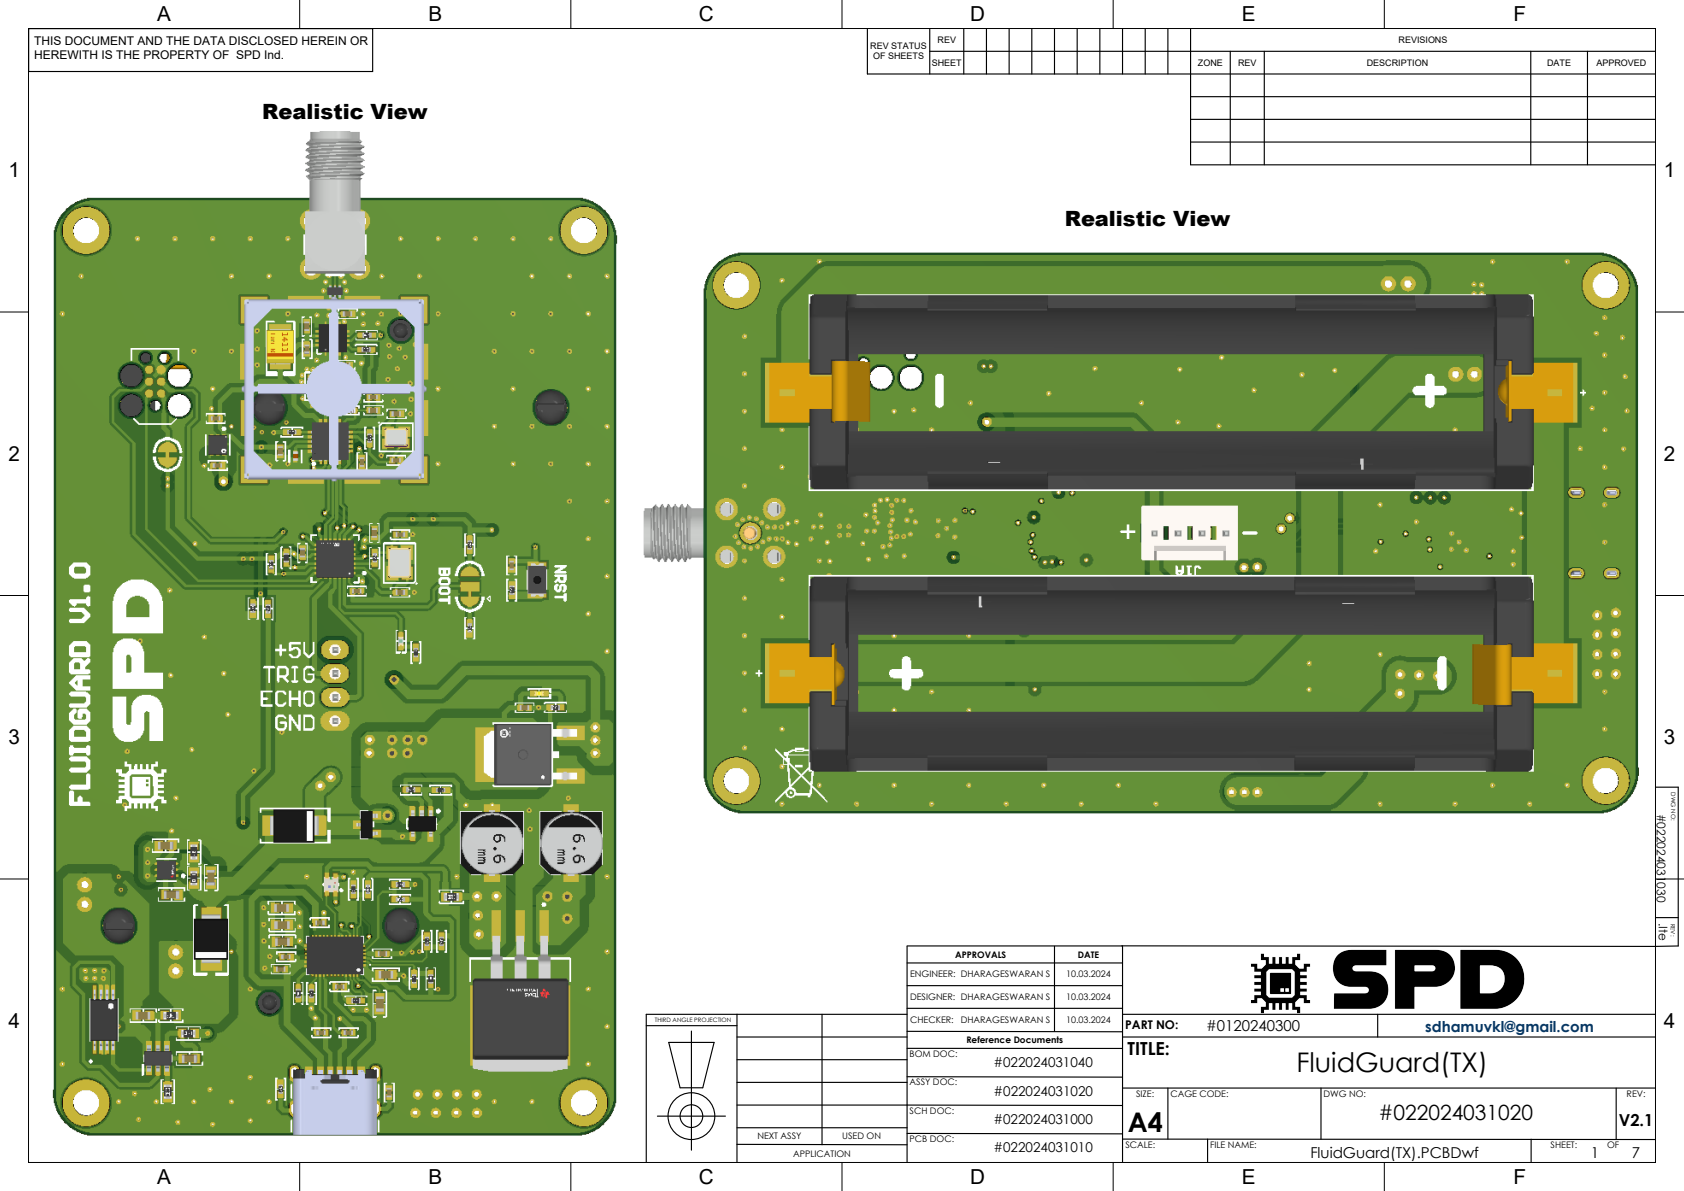
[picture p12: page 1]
sdhamuvkl@gmail.com; ZONE; REV; DESCRIPTION; DATE; APPROVED; REVISIONS; SHEET; REV STATUS OF SHEETS; REV:; SHEET:; DWG NO: #022024031030 .Ite; PART NO:; NEXT ASSY; USED ON; APPLICATION; FluidGuard(TX).PCBDwf #022024031010; FILE NAME:; Reference Documents #022024031040; SCH DOC:; PCB DOC:; ASSY DOC:; BOM DOC:; FluidGuard(TX); TITLE:; SCALE:; DWG NO:; SIZE:; CAGE CODE:; Realistic View

THIS DOCUMENT AND THE DATA DISCLOSED HEREIN OR
HEREWITH IS THE PROPERTY OF SPD Ind.

APPROVALS | DATE

ENGINEER: DHARAGESWARAN S | 10.03.2024

DESIGNER: DHARAGESWARAN S | 10.03.2024

THIRD ANGLE PROJECTION

CHECKER: DHARAGESWARAN S | 10.03.2024

1 | 1
R1C | Y1C

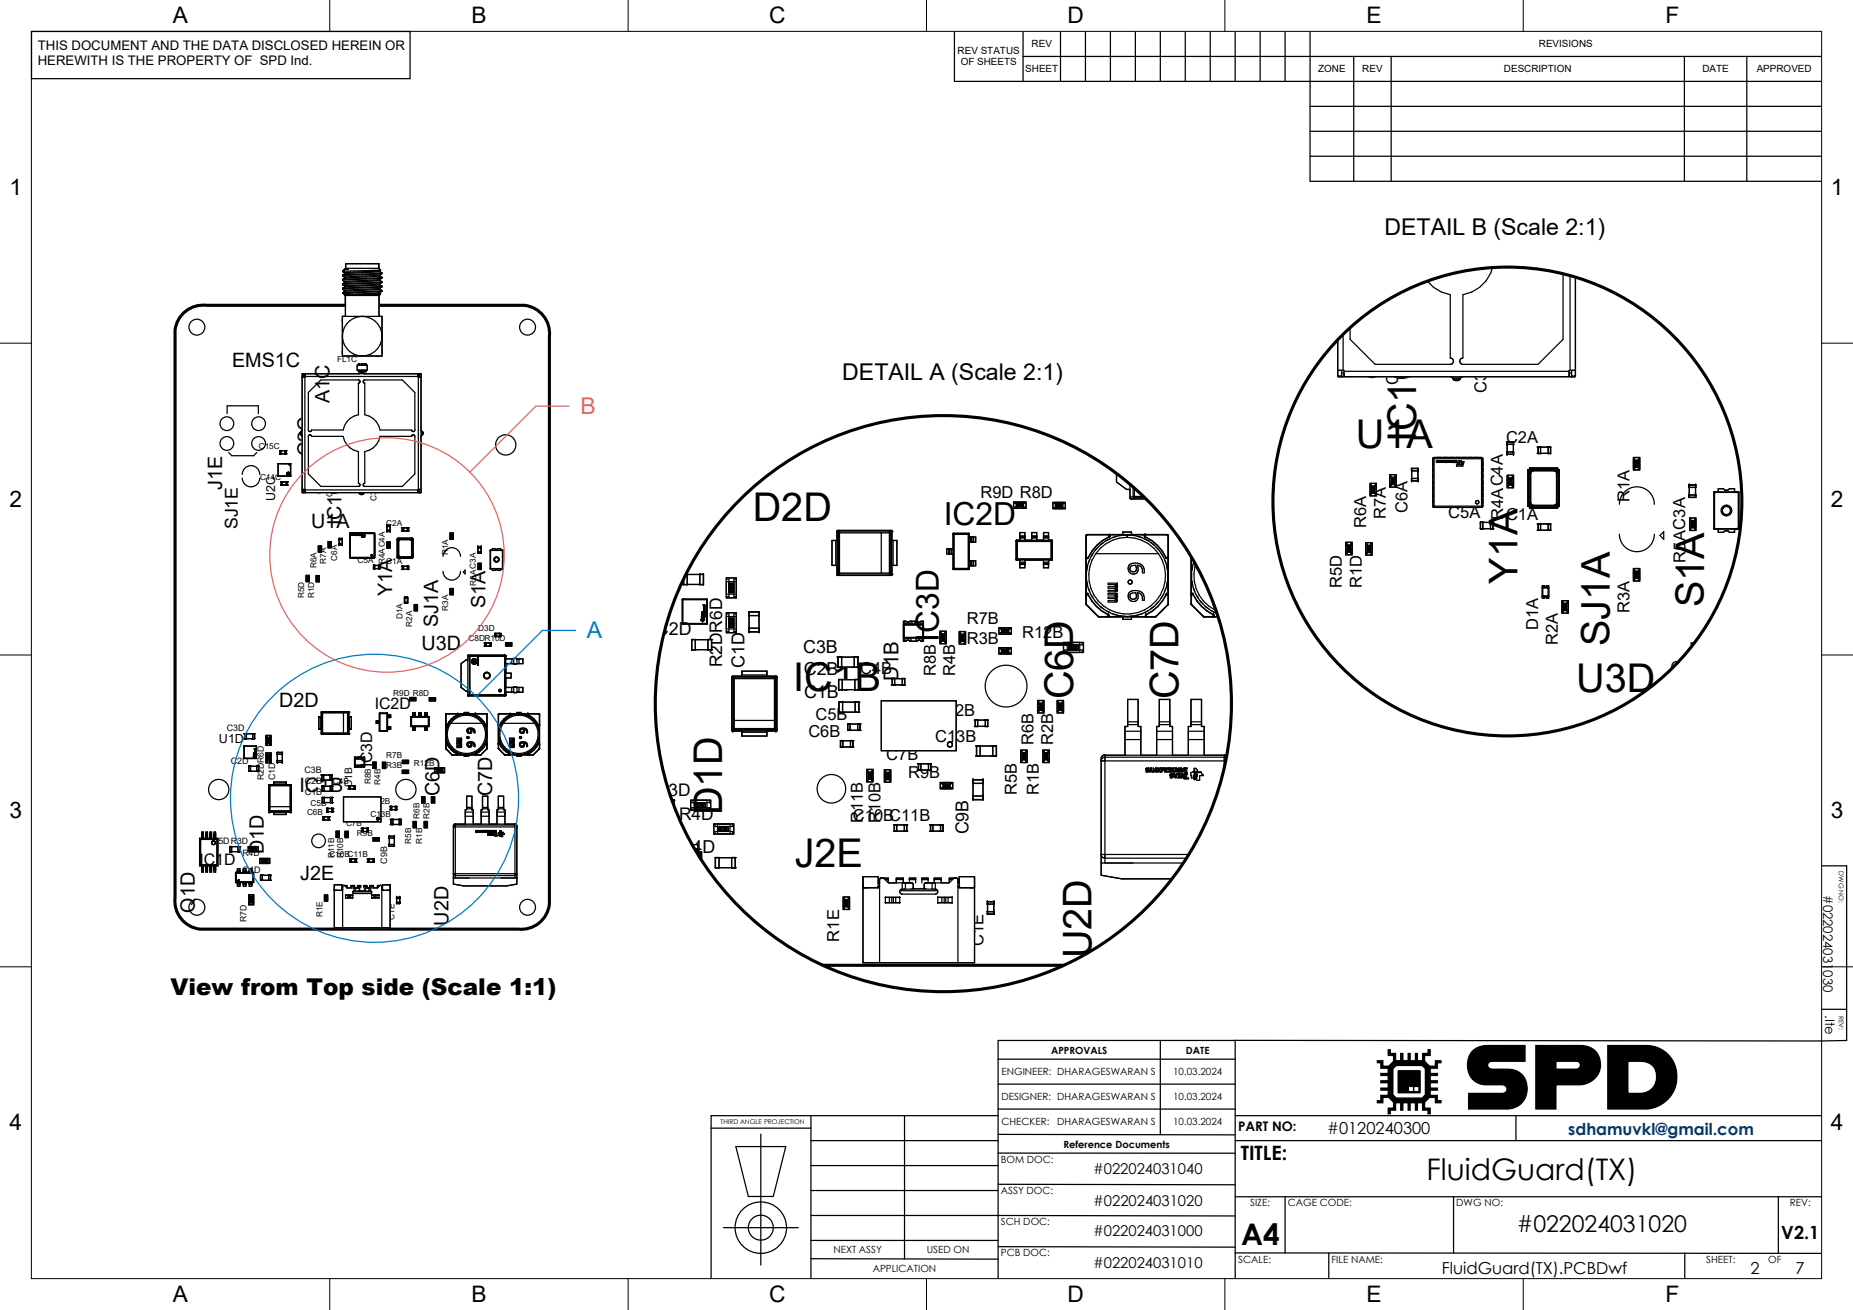
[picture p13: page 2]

View from Top side (Scale 1:1)

1 | 1

# Drill Drawing View (Scale 2:1)

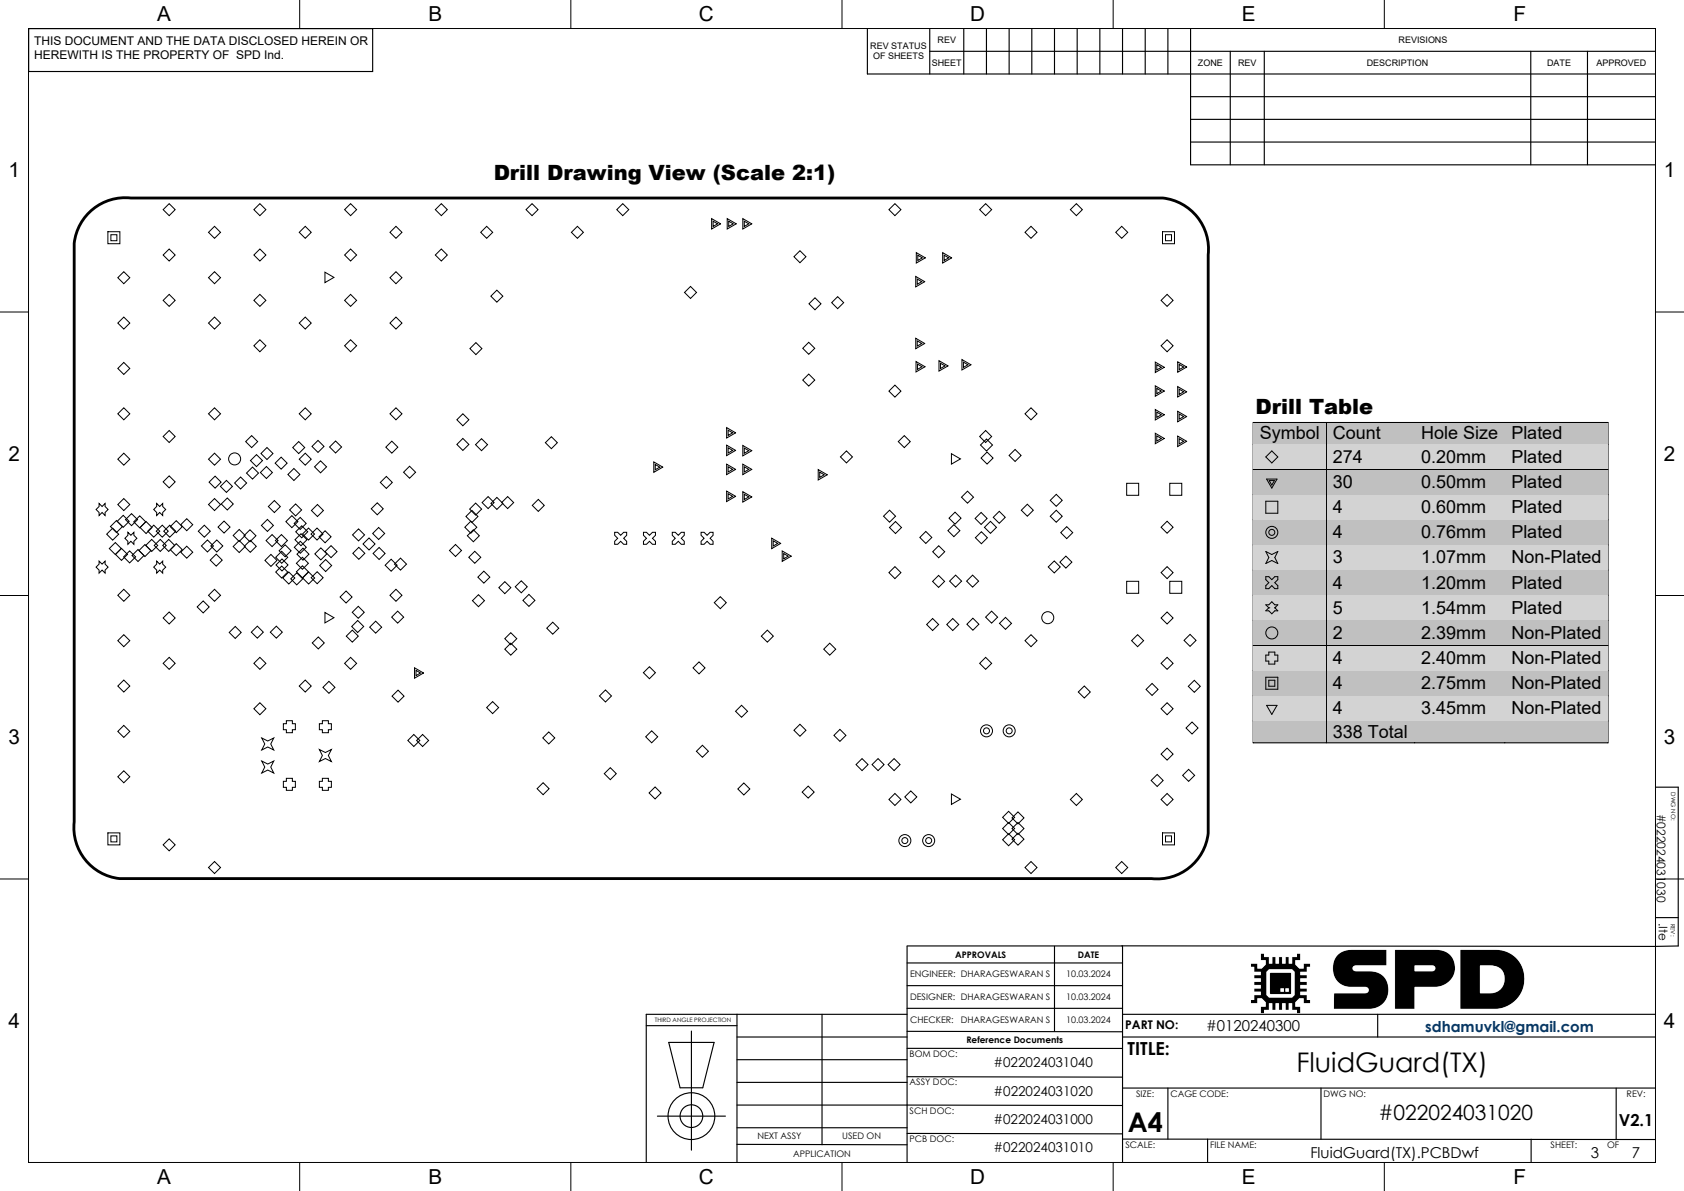
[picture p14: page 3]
DWG NO: #022024031030 .Ite; REV:; PART NO:; Reference Documents #022024031040; ASSY DOC:; BOM DOC:; FluidGuard(TX); TITLE:; Drill Table

Symbol | Count | Hole Size | Plated

274 | 0.20mm | Plated
30 | 0.50mm | Plated
4 | 0.60mm | Plated
4 | 0.76mm | Plated
3 | 1.07mm | Non-Plated
4 | 1.20mm | Plated
5 | 1.54mm | Plated
2 | 2.39mm | Non-Plated
4 | 2.40mm | Non-Plated
4 | 2.75mm | Non-Plated
4 | 3.45mm | Non-Plated
338 Total

APPROVALS | DATE

ENGINEER: DHARAGESWARAN S | 10.03.2024

DESIGNER: DHARAGESWARAN S | 10.03.2024

THIRD ANGLE PROJECTION

CHECKER: DHARAGESWARAN S | 10.03.2024

sdhamuvkl@gmail.com

1 | 1

# Top Layer (Scale 1.5:1)

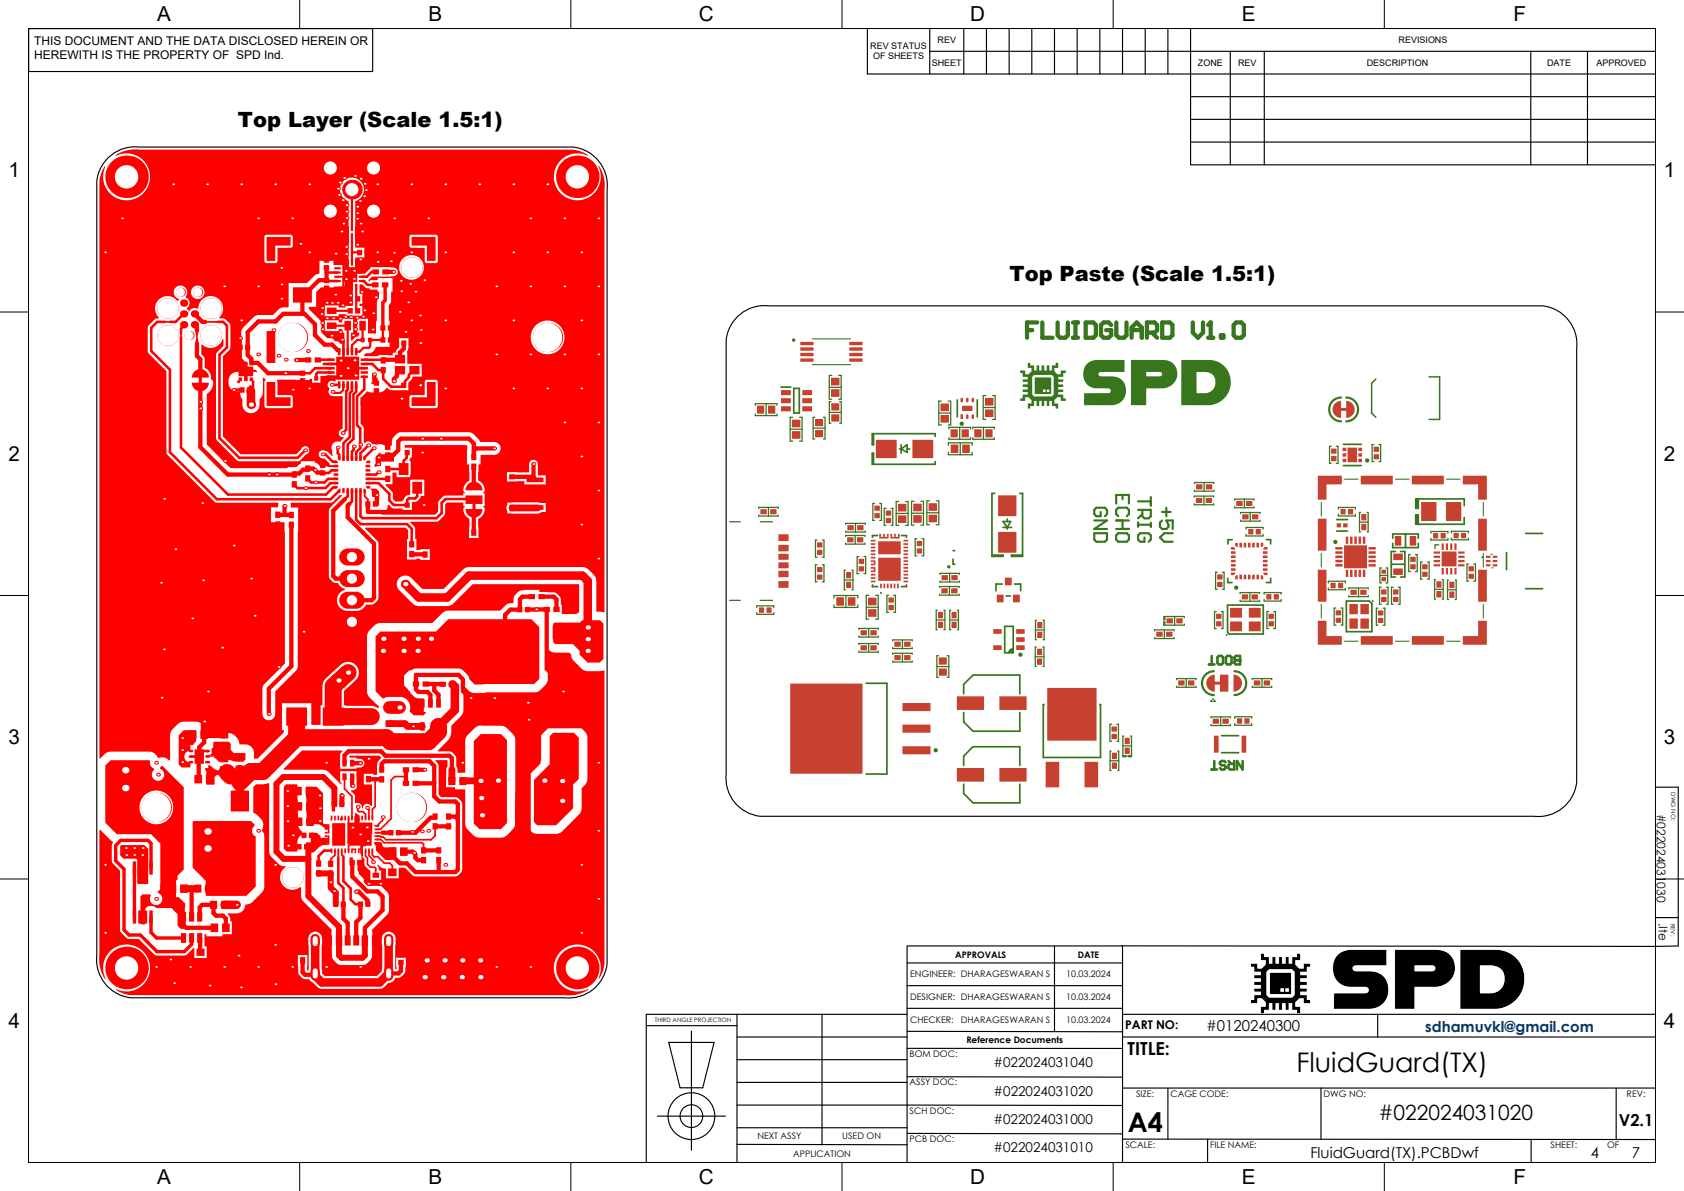
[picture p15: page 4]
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

Top Paste (Scale 1.5:1)

APPROVALS | DATE

ENGINEER: DHARAGESWARAN S | 10.03.2024

DESIGNER: DHARAGESWARAN S | 10.03.2024

THIRD ANGLE PROJECTION

CHECKER: DHARAGESWARAN S | 10.03.2024

sdhamuvkl@gmail.com

1 | 1

# Mid Layer 1(GND) (Scale 1.5:1)

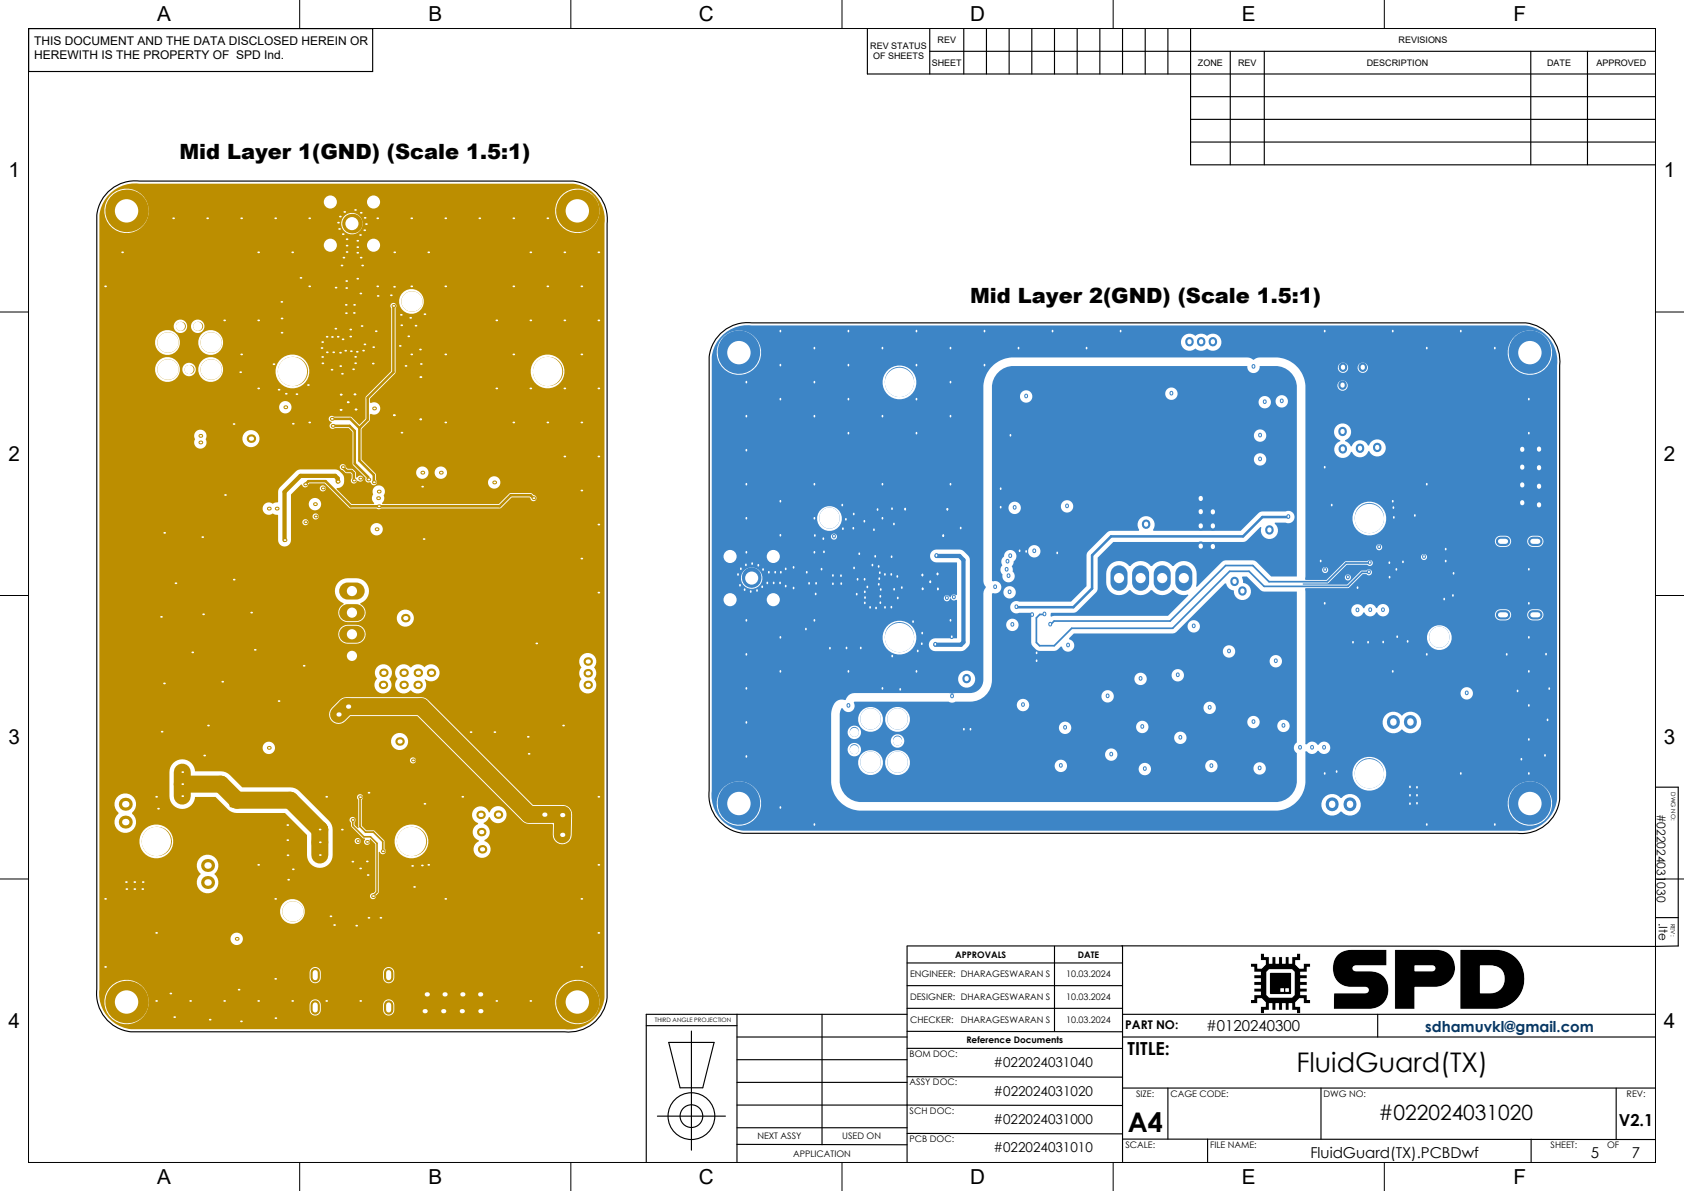
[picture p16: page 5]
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

Mid Layer 2(GND) (Scale 1.5:1)

APPROVALS | DATE

ENGINEER: DHARAGESWARAN S | 10.03.2024

DESIGNER: DHARAGESWARAN S | 10.03.2024

THIRD ANGLE PROJECTION

CHECKER: DHARAGESWARAN S | 10.03.2024

sdhamuvkl@gmail.com

1 | 1

# Bottom Layer (Scale 1.5:1)

DWG NO: #022024031030 .Ite; REV:; PART NO:; Reference Documents #022024031040; ASSY DOC:; BOM DOC:; FluidGuard(TX); TITLE:; Target Impedance 50 50 50 50; Calculated Impedance 50.02 50.02 50.02 50.02; Wide Trace Width 0.26mm 0.18mm 0.18mm 0.26mm; Narrow Trace Width 0.26mm 0.18mm 0.18mm 0.26mm; Clearance 0.13mm 0.13mm 0.13mm 0.13mm; Target Tolerance 5% 5% 5% 5%; Transmission Line Structure Table

Trace layer
Top Layer
Mid Layer 1(GND)
Mid Layer 2(GND)
Bottom Layer

Reference layers
Top Layer,Mid Layer 2(GND)
Mid Layer 1(GND),Bottom Layer

APPROVALS | DATE

ENGINEER: DHARAGESWARAN S | 10.03.2024

DESIGNER: DHARAGESWARAN S | 10.03.2024

THIRD ANGLE PROJECTION

CHECKER: DHARAGESWARAN S | 10.03.2024

sdhamuvkl@gmail.com

1 | 1
Designator | Name | Quantity


A1C | 0731000115 | 1
BT1D, BT2D | 1042P | 2

IC2D | LM321MFX/NOPB | 1
IC3D | FDN304PZ | 1
J1A | 0022272041 | 1

APPROVALS | DATE

ENGINEER: DHARAGESWARAN S | 10.03.2024

DESIGNER: DHARAGESWARAN S | 10.03.2024

THIRD ANGLE PROJECTION

CHECKER: DHARAGESWARAN S | 10.03.2024

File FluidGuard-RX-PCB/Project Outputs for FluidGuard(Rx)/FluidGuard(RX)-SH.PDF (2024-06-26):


THIS DOCUMENT AND THE DATA DISCLOSED HEREIN OR
HEREWITH IS THE PROPERTY OF SPD Ind.

@Y1 Given, CL = 12 pF
Parasitic Capcitance of FR-4 PCB ≈ 2.5pF Approx
And Cl1=Cl2, C ≈ 2*(CL-Cp)

ENG: DHARAGESWARAN S | 15.03.2024

DSN: DHARAGESWARAN S | 15.03.2024

FluidGuard(RX)-MCU BLOCK

Parasitic Capcitance,
Here, W, H, L are width, height, lenght of the PCB trace.
Er is Dielectric Constant of FR-4 PCB ≈ 4.5

CHK: DHARAGESWARAN S | 15.03.2024


@Y1 Given, CL = 12 pF
CL = (C'1 * C'2) / (C'1 + C'2) Here, C'1 = C1 + Cpcb + Ci1 & C'2 = C2 + Cpcb + Ci2
Intersic Capacitance of nRF24L01 was Ci1 = Ci2 = 1pF
Parasitic Capcitance of FR-4 PCB ≈ 1.5 pF Approx
And for C1 = C2, = > C^2 - 19C - 60 = 0 by Quadratic Eq we get C = 21.75 | -5.51

Parasitic Capcitance,
C' ≈ (Eo * Er * W) / H & Cpcb = C' * L
Here, W, H, L are width, height, lenght of the PCB trace.
Er is Dielectric Constant of FR-4 PCB ≈ 4.5

DSN: DHARAGESWARAN S | 15.03.2024

CHK: DHARAGESWARAN S | 15.03.2024


Only Fit Pot if
DigitalPot not
present.

ENG: DHARAGESWARAN S | 15.03.2024

DSN: DHARAGESWARAN S | 15.03.2024

CHK: DHARAGESWARAN S | 15.03.2024


THIS DOCUMENT AND THE DA
HEREWITH IS THE PROPERTY OF SPD In

ENG : DHARAGESWARAN S | 1 5.0 3.2 0 2 4

DSN: DHARAGESWARAN S | 1 5.0 3.2 0 2 4

CHK: DHARAGESWARAN S | 1 5.0 3.2 0 2 4


ENG: DHARAGESWARAN S | 15.03.2024

DSN: DHARAGESWARAN S | 15.03.2024

CHK: DHARAGESWARAN S | 15.03.2024


ENG : DHARAGESWARAN S | 1 5.0 3.2 0 2 4

DSN: DHARAGESWARAN S | 1 5.0 3.2 0 2 4

CHK: DHARAGESWARAN S | 1 5.0 3.2 0 2 4


ENG : DHARAGESWARAN S | 1 5.0 3.2 0 2 4

DSN: DHARAGESWARAN S | 1 5.0 3.2 0 2 4

CHK: DHARAGESWARAN S | 1 5.0 3.2 0 2 4

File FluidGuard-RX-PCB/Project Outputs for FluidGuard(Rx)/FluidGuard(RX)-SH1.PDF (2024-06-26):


THIS DOCUMENT AND THE DATA DISCLOSED HEREIN OR
HEREWITH IS THE PROPERTY OF SPD Ind.

@Y1 Given, CL = 12 pF
Parasitic Capcitance of FR-4 PCB ≈ 2.5pF Approx
And Cl1=Cl2, C ≈ 2*(CL-Cp)

ENG: DHARAGESWARAN S | 15.03.2024

DSN: DHARAGESWARAN S | 15.03.2024

FluidGuard(RX)-MCU BLOCK

Parasitic Capcitance,
Here, W, H, L are width, height, lenght of the PCB trace.
Er is Dielectric Constant of FR-4 PCB ≈ 4.5

CHK: DHARAGESWARAN S | 15.03.2024


@Y1 Given, CL = 12 pF
CL = (C'1 * C'2) / (C'1 + C'2) Here, C'1 = C1 + Cpcb + Ci1 & C'2 = C2 + Cpcb + Ci2
Intersic Capacitance of nRF24L01 was Ci1 = Ci2 = 1pF
Parasitic Capcitance of FR-4 PCB ≈ 1.5 pF Approx
And for C1 = C2, = > C^2 - 19C - 60 = 0 by Quadratic Eq we get C = 21.75 | -5.51

Parasitic Capcitance,
C' ≈ (Eo * Er * W) / H & Cpcb = C' * L
Here, W, H, L are width, height, lenght of the PCB trace.
Er is Dielectric Constant of FR-4 PCB ≈ 4.5

DSN: DHARAGESWARAN S | 15.03.2024

CHK: DHARAGESWARAN S | 15.03.2024


Only Fit Pot if
DigitalPot not
present.

ENG: DHARAGESWARAN S | 15.03.2024

DSN: DHARAGESWARAN S | 15.03.2024

CHK: DHARAGESWARAN S | 15.03.2024


THIS DOCUMENT AND THE DA
HEREWITH IS THE PROPERTY OF SPD In

ENG : DHARAGESWARAN S | 1 5.0 3.2 0 2 4

DSN: DHARAGESWARAN S | 1 5.0 3.2 0 2 4

CHK: DHARAGESWARAN S | 1 5.0 3.2 0 2 4


ENG: DHARAGESWARAN S | 15.03.2024

DSN: DHARAGESWARAN S | 15.03.2024

CHK: DHARAGESWARAN S | 15.03.2024


ENG : DHARAGESWARAN S | 1 5.0 3.2 0 2 4

DSN: DHARAGESWARAN S | 1 5.0 3.2 0 2 4

CHK: DHARAGESWARAN S | 1 5.0 3.2 0 2 4


ENG : DHARAGESWARAN S | 1 5.0 3.2 0 2 4

DSN: DHARAGESWARAN S | 1 5.0 3.2 0 2 4

CHK: DHARAGESWARAN S | 1 5.0 3.2 0 2 4

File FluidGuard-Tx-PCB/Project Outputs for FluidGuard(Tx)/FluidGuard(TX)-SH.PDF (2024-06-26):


THIS DOCUMENT AND THE DA
HEREWITH IS THE PROPERTY OF SPD In

ENG : DHARAGESWARAN S | 1 0.0 3.2 0 2 4

DSN: DHARAGESWARAN S | 1 0.0 3.2 0 2 4

CHK: DHARAGESWARAN S | 1 0.0 3.2 0 2 4


THIS DOCUMENT AND THE DATA DISCLOSED HEREIN OR
HEREWITH IS THE PROPERTY OF SPD Ind.

ENG: DHARAGESWARAN S | 10.03.2024

DSN: DHARAGESWARAN S | 10.03.2024

CHK: DHARAGESWARAN S | 10.03.2024

Red, Green, Blue (RGB)


@Y1 Given, CL = 12 pF
CL = (C'1 * C'2) / (C'1 + C'2) Here, C'1 = C1 + Cpcb + Ci1 & C'2 = C2 + Cpcb + Ci2
Intersic Capacitance of nRF24L01 was Ci1 = Ci2 = 1pF
Parasitic Capcitance of FR-4 PCB ≈ 1.5 pF Approx
And for C1 = C2, = > C^2 - 19C - 60 = 0 by Quadratic Eq we get C = 21.75 | -5.51

Parasitic Capcitance,
C' ≈ (Eo * Er * W) / H & Cpcb = C' * L
Here, W, H, L are width, height, lenght of the PCB trace.
Er is Dielectric Constant of FR-4 PCB ≈ 4.5

DSN: DHARAGESWARAN S | 10.03.2024

CHK: DHARAGESWARAN S | 10.03.2024


R1 + R2 <= Vout/(Ifb*100)
Vout = Vfb(1+R1/R2)
For Better Accurency Ifb = 50nA & Vfb = 0.8V So, R1 + R2 <= 1.8 MOhm

ENG: DHARAGESWARAN S | 10.03.2024

DSN: DHARAGESWARAN S | 10.03.2024

CHK: DHARAGESWARAN S | 10.03.2024


THIS DOCUMENT AND THE DA
HEREWITH IS THE PROPERTY OF SPD In

ENG : DHARAGESWARAN S | 1 0.0 3.2 0 2 4

DSN: DHARAGESWARAN S | 1 0.0 3.2 0 2 4

CHK: DHARAGESWARAN S | 1 0.0 3.2 0 2 4

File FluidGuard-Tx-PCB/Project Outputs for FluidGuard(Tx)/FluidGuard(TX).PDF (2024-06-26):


THIS DOCUMENT AND THE DA
HEREWITH IS THE PROPERTY OF SPD In

ENG : DHARAGESWARAN S | 1 0.0 3.2 0 2 4

DSN: DHARAGESWARAN S | 1 0.0 3.2 0 2 4

CHK: DHARAGESWARAN S | 1 0.0 3.2 0 2 4


THIS DOCUMENT AND THE DATA DISCLOSED HEREIN OR
HEREWITH IS THE PROPERTY OF SPD Ind.

ENG: DHARAGESWARAN S | 10.03.2024

DSN: DHARAGESWARAN S | 10.03.2024

CHK: DHARAGESWARAN S | 10.03.2024

Red, Green, Blue (RGB)


@Y1 Given, CL = 12 pF
CL = (C'1 * C'2) / (C'1 + C'2) Here, C'1 = C1 + Cpcb + Ci1 & C'2 = C2 + Cpcb + Ci2
Intersic Capacitance of nRF24L01 was Ci1 = Ci2 = 1pF
Parasitic Capcitance of FR-4 PCB ≈ 1.5 pF Approx
And for C1 = C2, = > C^2 - 19C - 60 = 0 by Quadratic Eq we get C = 21.75 | -5.51

Parasitic Capcitance,
C' ≈ (Eo * Er * W) / H & Cpcb = C' * L
Here, W, H, L are width, height, lenght of the PCB trace.
Er is Dielectric Constant of FR-4 PCB ≈ 4.5

DSN: DHARAGESWARAN S | 10.03.2024

CHK: DHARAGESWARAN S | 10.03.2024


R1 + R2 <= Vout/(Ifb*100)
Vout = Vfb(1+R1/R2)
For Better Accurency Ifb = 50nA & Vfb = 0.8V So, R1 + R2 <= 1.8 MOhm

ENG: DHARAGESWARAN S | 10.03.2024

DSN: DHARAGESWARAN S | 10.03.2024

CHK: DHARAGESWARAN S | 10.03.2024


THIS DOCUMENT AND THE DA
HEREWITH IS THE PROPERTY OF SPD In

ENG : DHARAGESWARAN S | 1 0.0 3.2 0 2 4

DSN: DHARAGESWARAN S | 1 0.0 3.2 0 2 4

CHK: DHARAGESWARAN S | 1 0.0 3.2 0 2 4

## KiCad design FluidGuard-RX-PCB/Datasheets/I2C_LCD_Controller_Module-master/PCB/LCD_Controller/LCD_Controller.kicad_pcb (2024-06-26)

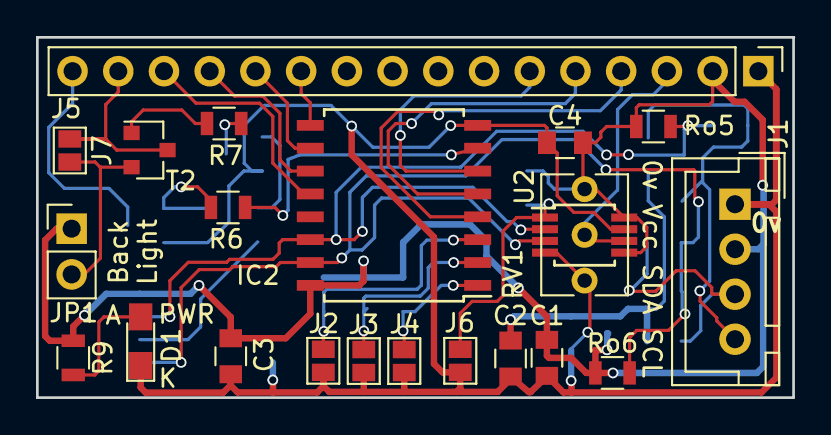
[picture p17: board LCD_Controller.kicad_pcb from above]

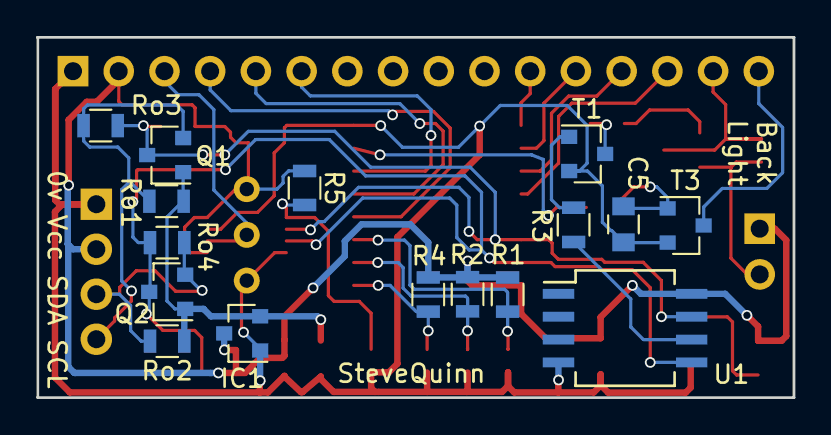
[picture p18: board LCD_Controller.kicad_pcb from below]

Board: 2 copper layers, 42.0 x 20.0 mm, 38 parts (16 on the bottom side), 29 nets.

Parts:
C1, C2: 1uF Ceramic; C_0805
C3, C4, C5: 0.1uF; C_0805
D1: RED LED; LED_0805_HandSoldering
IC1: XC6206; SOT-23
IC2: PCF8574A; SOIC-16W_7.5x10.3mm_Pitch1.27mm
J1: LCD; JST_XH_B04B-XH-A_04x2.50mm_Straight
J2, J3, J4, J6, J7: GS2
J5: To LCD; Pin_Header_Straight_1x16_Pitch2.54mm
JP1: Jumper; Pin_Header_Straight_1x02_Pitch2.54mm
Q1, Q2: DMG3414U; SOT-23
R1, R2, R4, R5: 10K; R_0805
R3, R6, R7, R9: 1K; R_0805
RV1: 10K; Potentiometer_Trimmer_Vishay_T73XW_Vertical
Ro1, Ro2, Ro5, Ro6: 4K7; R_0805
Ro3, Ro4: 0R; R_0805
T1, T3: BCW66GLT1G; SOT-23
T2: BC858C; SOT-23
U1: ATTINY85-20PU; SO-8_5.3x6.2mm_Pitch1.27mm
U2: MCP4561-103E/MS; MSOP-8_3x3mm_Pitch0.65mm

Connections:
+3V3: C2.2, IC1.2, Q1.1, Q2.1, Ro1.1, Ro2.1
+5V: C1.2, C3.2, C4.2, IC1.3, IC2.16, J1.2, J5.2, JP1.1, R1.1, R2.1, R4.1, R5.1, R9.1, RV1.1, Ro5.1, Ro6.1, U1.8, U2.5, U2.8
GND: C1.1, C2.1, C3.1, C4.1, C5.2, D1.1, IC1.1, IC2.8, J1.1, J2.2, J3.2, J4.2, J5.1, J6.2, RV1.3, T1.2, T3.2, U1.4, U2.4, U2.7
unnamed: C5.1, R6.1, T3.1
unnamed: D1.2, R9.2
unnamed: IC2.1, J4.1, R4.2
unnamed: IC2.2, J3.1, R2.2
unnamed: IC2.3, J2.1, R1.2
unnamed: IC2.4, J5.4
unnamed: IC2.5, J5.5
unnamed: IC2.6, J5.6
unnamed: IC2.7, R6.2
unnamed: IC2.9, J5.11
unnamed: IC2.10, J5.12
unnamed: IC2.11, J5.13
unnamed: IC2.12, J5.14
unnamed: J5.3, RV1.2, U2.6
unnamed: J5.15, J7.1, T2.3
unnamed: J5.16, T3.3
unnamed: J6.1, R5.2, U2.1
unnamed: J7.2, JP1.2, T2.2
unnamed: R3.1, T1.1
unnamed: R3.2, U1.6
unnamed: R7.1, T2.1
unnamed: R7.2, T1.3
SCL: J1.4, Q1.2, Ro1.2, Ro3.1
SCL_H: IC2.14, Q1.3, Ro3.2, Ro5.2, U1.7, U2.2
SDA: J1.3, Q2.2, Ro2.2, Ro4.1
SDA_H: IC2.15, Q2.3, Ro4.2, Ro6.2, U1.5, U2.3

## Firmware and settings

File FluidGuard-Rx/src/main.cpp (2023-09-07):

#include <Arduino.h>
#include <SPI.h>
#include <RF24.h>
#include <LiquidCrystal.h>

RF24 radio(9, 10); // Set CE and CSN pins for NRF24L01+ module

LiquidCrystal lcd(2, 3, 4, 5, 6, 7); // LCD module connections (change these pins as per your wiring)
const byte address[6] = "00001";      // Set the transmitting address as a byte array

const int buttonPinA0 = A0; // Push button A0 pin
const int buttonPinA1 = A1; // Push button A1 pin
const int relayPin = 8;     // Relay control pin

int relayState = LOW;           // Initial state of the relay
bool buttonPressedA0 = false;   // Track the button A0 state
bool buttonPressedA1 = false;   // Track the button A1 state
unsigned long lastReceivedTime; // Variable to store the last time a percentage value was received
const unsigned long timeoutDuration = 5000; // Timeout duration in milliseconds (e.g., 5000 = 5 seconds)

bool isTemporaryFailDisplayed = false; // Flag to track if "Temporary Fail" is currently displayed

const int distanceMax = 120; // Maximum distance for bar graph display
const int highThreshold = 117; // High threshold for relay state
const int lowThreshold = 50; // Low threshold for relay state

// Function to display the bar graph on the LCD
void displayBarGraph(int value, int maxValue)
{
  int numBars = map(value, 0, maxValue, 0, 16);     // Map the value to the number of bars (0-16)
  int percentage = map(value, 0, maxValue, 0, 100); // Calculate the percentage

  lcd.setCursor(0, 0); // Set the cursor to the first column of the first row

  for (int i = 0; i < numBars; i++)
  {
    lcd.write(0xFF); // Display a filled block character
  }

  lcd.setCursor(0, 1); // Set the cursor to the first column of the second row

  lcd.print(percentage); // Display the percentage
  lcd.print("%");        // Display the percentage symbol

  lcd.print("       "); // Clear any remaining characters on the line
}

// Function to update the relay state based on distance percentage
void updateRelayState(int percentage)
{
  if (isTemporaryFailDisplayed || percentage >= highThreshold)
  {
    relayState = LOW; // Turn off the relay
  }
  else if (percentage <= lowThreshold)
  {
    relayState = HIGH; // Turn on the relay
  }

  digitalWrite(relayPin, relayState);
}

// Function to display the "Temporary Fail" message
void displayTemporaryFail()
{
  if (!isTemporaryFailDisplayed)
  {
    lcd.clear(); // Clear the LCD screen
    lcd.print("Temporary Fail"); // Display the warning message
    isTemporaryFailDisplayed = true;
  }
}

// Function to clear the "Temporary Fail" message
void clearTemporaryFail()
{
  if (isTemporaryFailDisplayed)
  {
    lcd.clear(); // Clear the LCD screen
    isTemporaryFailDisplayed = false;
  }
}

// Function to read and debounce the button state
bool readButtonState(int buttonPin, bool& buttonState)
{
  bool currentState = digitalRead(buttonPin);
  if (currentState != buttonState)
  {
    delay(50); // Debounce delay
    currentState = digitalRead(buttonPin);
    if (currentState != buttonState)
    {
      buttonState = currentState;
      return true; // Button state changed
    }
  }
  return false; // Button state unchanged
}

void setup()
{
  lcd.begin(16, 2); // Set the LCD dimensions (16 columns and 2 rows)

  radio.begin();
  radio.openReadingPipe(0, address);
  radio.setPALevel(RF24_PA_MAX);
  radio.setChannel(75);
  radio.setDataRate(RF24_250KBPS);
  radio.startListening();

  pinMode(buttonPinA0, INPUT);
  pinMode(buttonPinA1, INPUT);
  pinMode(relayPin, OUTPUT);

  digitalWrite(relayPin, LOW); // Set initial state of the relay

  lastReceivedTime = millis(); // Initialize the lastReceivedTime variable with the current time
}

void loop()
{
  if (radio.available())
  {
    unsigned long distance;
    radio.read(&distance, sizeof(distance)); // Receive the sonar distance value from the transmitter

    lastReceivedTime = millis(); // Update the lastReceivedTime variable

    clearTemporaryFail(); // Clear the "Temporary Fail" message if it was previously displayed

    lcd.clear();                    // Clear the LCD screen
    displayBarGraph(distance, distanceMax);

    updateRelayState(distance); // Update the relay state based on distance percentage
  }

  // Check if the timeout duration has elapsed since the last received percentage value
  if (millis() - lastReceivedTime >= timeoutDuration)
  {
    displayTemporaryFail(); // Display the "Temporary Fail" message
    updateRelayState(0);    // Stop relay operation (set relayState to LOW)
    // Perform any additional actions as needed
  }

  // Read and handle button A0 state change
  if (readButtonState(buttonPinA0, buttonPressedA0))
  {
    relayState = buttonPressedA0 ? HIGH : LOW;
    digitalWrite(relayPin, relayState);
  }

  // Read and handle button A1 state change
  if (readButtonState(buttonPinA1, buttonPressedA1))
  {
    relayState = buttonPressedA1 ? HIGH : LOW;
    digitalWrite(relayPin, relayState);
  }
}

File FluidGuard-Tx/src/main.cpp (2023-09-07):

#include <Arduino.h>
#include <SPI.h>
#include <RF24.h>

RF24 radio(9, 10);  // Set CE and CSN pins for NRF24L01+ module

const byte address[6] = "00001";  // Set the transmitting address as a byte array

const int triggerPin = 6;  // Connect the trigger pin of the HC-SR04 to digital pin 2
const int echoPin = 7;  // Connect the echo pin of the HC-SR04 to digital pin 3

unsigned long previousMillis = 0;  // Stores the previous time
const long interval = 1000;  // Interval between measurements in milliseconds

const int numSamples = 5;  // Number of distance samples to collect
int distances[numSamples];  // Array to store the distance samples
int currentIndex = 0;  // Index of the current distance sample

const int maxDistance = 125;  // Maximum distance limit in centimeters

void setup() {
  Serial.begin(115200);
  radio.begin();
  radio.openWritingPipe(address);
  radio.setPALevel(RF24_PA_MAX);
  radio.setChannel(75); 
  radio.setDataRate(RF24_250KBPS);
  radio.stopListening();
  
  pinMode(triggerPin, OUTPUT);
  pinMode(echoPin, INPUT);
  
  // Initialize the distances array with an initial value
  for (int i = 0; i < numSamples; i++) {
    distances[i] = -1;
  }
}

void loop() {
  unsigned long currentMillis = millis();  // Current time
  
  // Check if the interval has passed
  if (currentMillis - previousMillis >= interval) {
    previousMillis = currentMillis;  // Update the previous time
    
    long duration, distance;
    
    // Send a pulse to the trigger pin to start the measurement
    digitalWrite(triggerPin, LOW);
    delayMicroseconds(2);
    digitalWrite(triggerPin, HIGH);
    delayMicroseconds(10);
    digitalWrite(triggerPin, LOW);
    
    // Measure the duration of the pulse from the echo pin
    duration = pulseIn(echoPin, HIGH);
    
    // Calculate the distance in centimeters
    distance = duration / 58.2;
    
    // Apply error reduction using indexing approach
    if (distance >= 2 && distance <= maxDistance) {
      distances[currentIndex] = maxDistance - distance;  // Reverse the measurement
      currentIndex = (currentIndex + 1) % numSamples;
    }
    
    // Calculate the average distance
    int sum = 0;
    int validSamples = 0;
    for (int i = 0; i < numSamples; i++) {
      if (distances[i] != -1) {
        sum += distances[i];
        validSamples++;
      }
    }
    int averageDistance = (validSamples > 0) ? (sum / validSamples) : -1;
    
    radio.write(&averageDistance, sizeof(averageDistance));  // Send the average distance value wirelessly to the receiver
    Serial.println(averageDistance);
  }
}
